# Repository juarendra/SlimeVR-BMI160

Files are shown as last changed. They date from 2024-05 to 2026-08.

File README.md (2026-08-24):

# SlimeVR-BMI160 DIY Tracker





**SlimeVR-BMI160** adalah proyek tracker full-body DIY (Do It Yourself) berbasis ESP32 dan sensor IMU BMI160, dikembangkan oleh [Positron Electronik](https://www.tokopedia.com/positronelectronic). Solusi ini merupakan alternatif hemat biaya dari tracker SlimeVR original, dengan tetap mempertahankan performa tinggi untuk pengalaman VR yang imersif.

<p align="center">
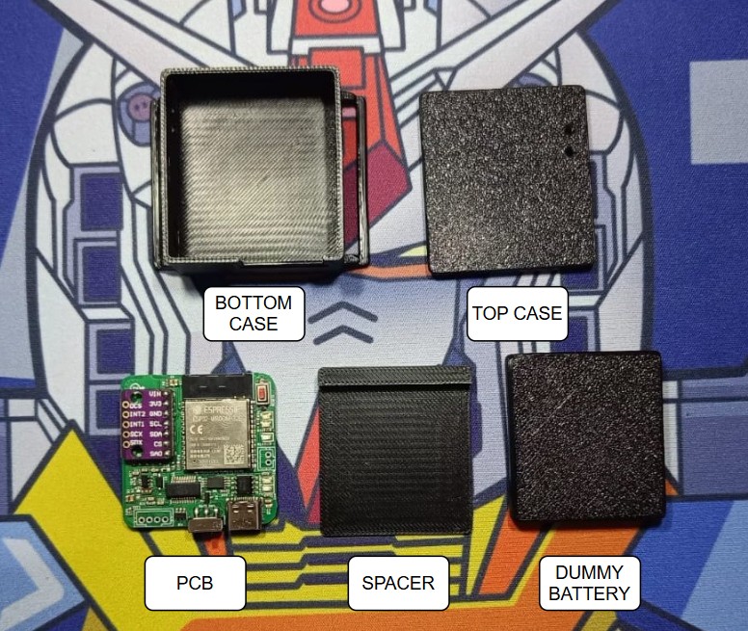
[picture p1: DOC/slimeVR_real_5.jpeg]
  
</p>

## ⚡ Fitur Unggulan
- **Mikrokontroler**: ESP32-WROOM-32 (WiFi + BLE)
- **Sensor IMU**: BMI160 (header socket, mudah diganti)
- **Manajemen Daya**: USB-C atau LiPo 1S, charger TP4056 + proteksi DW01A
- **Konektor I2C**: Port ekspansi untuk sensor tambahan
- **LED Indikator**: 5 LED untuk status pengisian, koneksi, dan serial
- **Tombol**: Reset & power switch

## 🚀 Cara Penggunaan

### 📦 Isi Paket (untuk produk jadi)
- 1 Unit tracker SlimeVR-BMI160
- 1 Baterai LiPo (terpasang)

### 🔋 Pengisian Daya
- Colokkan USB-C: LED **biru** menyala saat mengisi, **merah** saat penuh.

### 🌐 Flash & Konfigurasi WiFi (Metode Termudah)
Gunakan **Web Installer** tanpa instalasi software:
1. Buka [SlimeVR BMI160 Web Installer](https://juarendra.github.io/SlimeVR-BMI160/) di Chrome/Edge (PC).
2. Hubungkan tracker via USB.
3. Klik **Install Firmware**, lalu masukkan SSID & Password WiFi.
4. Tunggu hingga proses selesai dan tracker terhubung ke server SlimeVR.

> **Catatan**: Web Installer menggunakan Web Serial, jadi pastikan browser mendukung (Chrome/Edge).

### 🛠️ Metode Manual (untuk Developer)
Jika Anda ingin mengembangkan atau mengompilasi firmware sendiri, ikuti panduan lengkap di:
➡️ **[Panduan Flashing Manual](./FIRMWARE/README.md)**

## 📂 Struktur Repositori
| Direktori | Isi |
|---|-----|
| `/PCB` | Desain PCB (EAGLE) dan file Gerber |
| `/HARDWARE` | Model 3D case (STL) dan dimensi |
| `/FIRMWARE` | Source code firmware (PlatformIO) dan file .bin compiled |
| `/site` | Web Installer (HTML, CSS, JS, manifest) |
| `/DOC` | Dokumentasi, gambar, BOM, datasheet |
| `/scripts` | Script otomatisasi (QA, release) |

## 🔧 Untuk Pengembang (DIY)
Jika Anda ingin merakit sendiri:
1. **Rakit Hardware**: Gunakan file PCB dari `/PCB/CAD-CAM`, BOM dari `/DOC/BOM_SlimeVRDiyModular.csv`, dan case 3D dari `/HARDWARE/case`.
2. **Flash Firmware**: Ikuti panduan di `/FIRMWARE/README.md`.
3. **Verifikasi**: Gunakan serial monitor untuk memastikan koneksi WiFi dan sensor.

## 🐛 Pemecahan Masalah Umum
- **Tracker tidak muncul di server**: Pastikan SSID/password benar, PC dan tracker satu jaringan, saklar ON.
- **LED mati total**: Cek saklar, charge baterai via USB-C.

## 📖 Dokumentasi Lengkap
- [Dokumentasi Software (PDF)](./DOC/SOFTWARE_USAGE.pdf) — panduan detail penggunaan web installer dan manual.

<details>
<summary><strong>📐 Detail Teknis dan Galeri</strong></summary>

| Fitur | Komponen |
|---|---|
| Mikrokontroler | ESP32-WROOM-32 |
| Sensor IMU | BMI160 |
| USB-to-Serial | FTDI FT231XS |
| Charger | TP4056 |
| Proteksi Baterai | DW01A + FS8205A |
| Regulator | M3406 (3.3V 800mA) |

**Diagram Pinout**:
<p align="center">
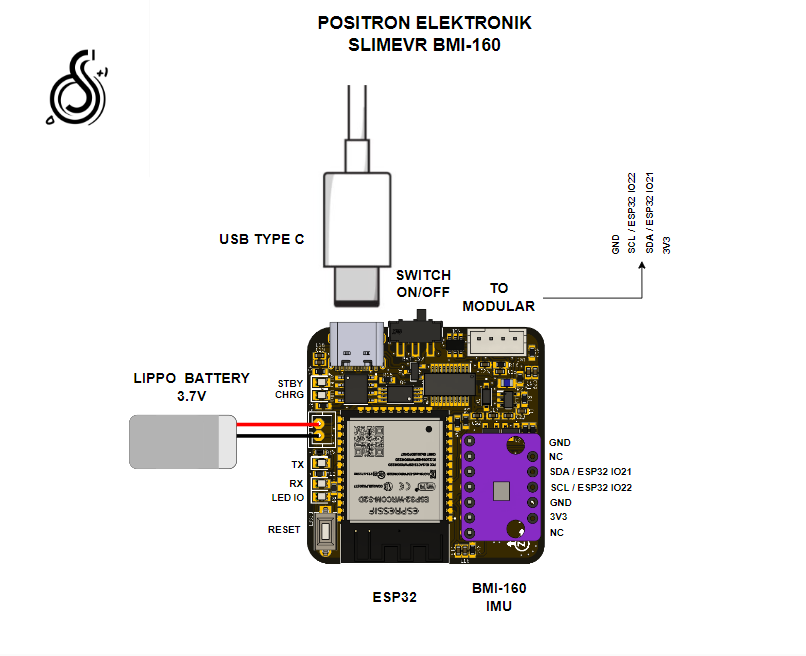
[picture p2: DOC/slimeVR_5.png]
  
</p>

**Dimensi Board**: [PDF](https://github.com/juarendra/SlimeVR-BMI160/blob/main/HARDWARE/dimension_SlimeVR.pdf)

**Galeri**:
<p align="center">
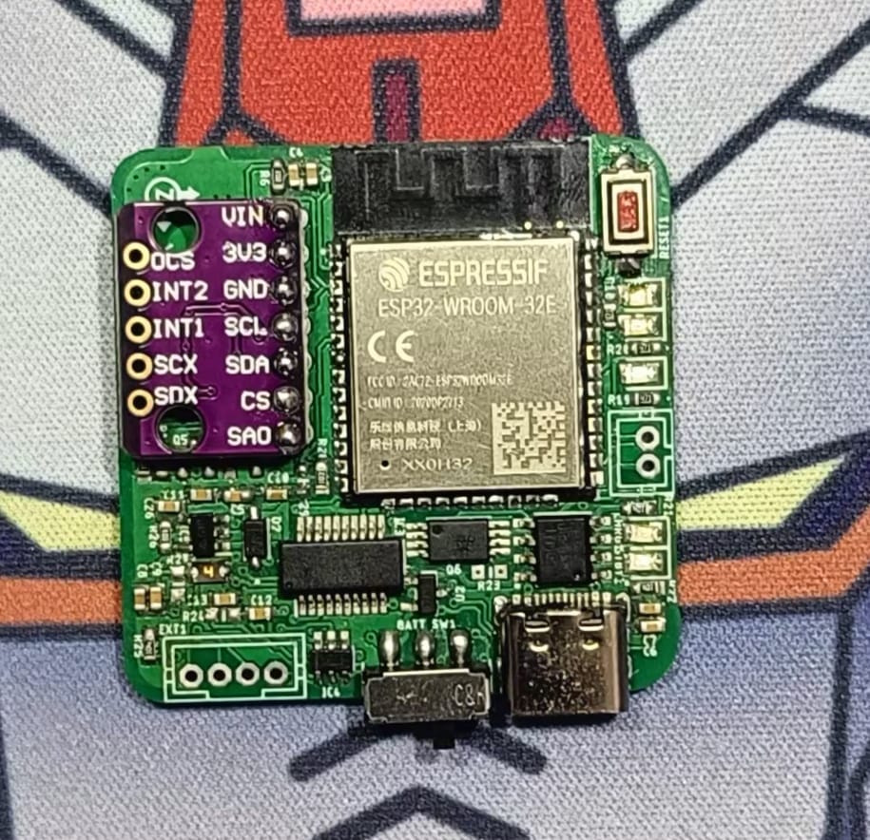
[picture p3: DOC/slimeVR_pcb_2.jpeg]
  
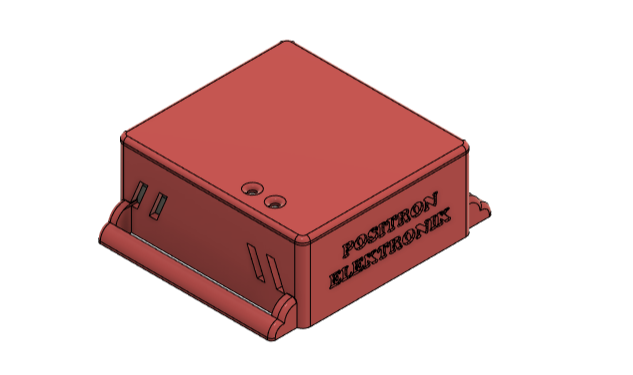
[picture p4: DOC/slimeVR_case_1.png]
  
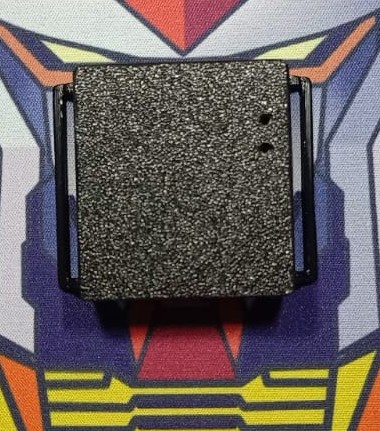
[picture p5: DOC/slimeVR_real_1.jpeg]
  
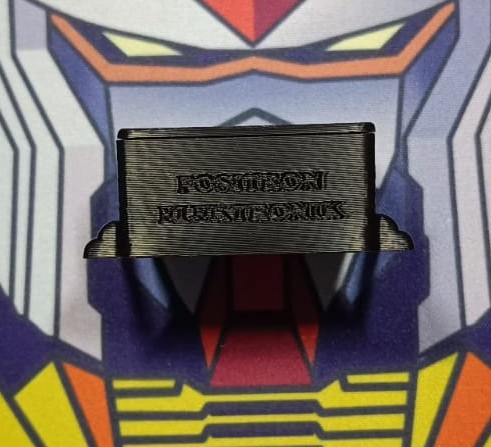
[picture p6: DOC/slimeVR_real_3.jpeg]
  
</p>
</details>

## ❓ FAQ
*Segera hadir.*

## 🤝 Kontribusi
Pull request dan saran sangat diterima! Silakan buka issue di GitHub.

## 📜 Lisensi
MIT License © 2024 Positron Electronik

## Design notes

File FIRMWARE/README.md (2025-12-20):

# Panduan Flashing Firmware SlimeVR untuk ESP32

Dokumen ini menjelaskan cara melakukan instalasi, konfigurasi, dan flashing firmware SlimeVR ke board ESP32 menggunakan Visual Studio Code dan PlatformIO.

## Daftar Isi
1. [Alat yang Dibutuhkan](#1-alat-yang-dibutuhkan)
2. [Instalasi Perangkat Lunak](#2-instalasi-perangkat-lunak)
    - [Download dan Instal Visual Studio Code](#a-download-dan-instal-visual-studio-code)
    - [Instal Ekstensi PlatformIO IDE](#b-instal-ekstensi-platformio-ide)
3. [Persiapan Firmware](#3-persiapan-firmware)
    - [Download Kode Firmware](#a-download-kode-firmware)
    - [Buka Proyek di VS Code](#b-buka-proyek-di-vs-code)
4. [Konfigurasi Wi-Fi (Hardcode)](#4-konfigurasi-wi-fi-hardcode)
5. [Proses Flashing](#5-proses-flashing)
    - [A. Hapus Flash (Erase Flash)](#a-hapus-flash-erase-flash---opsional-tapi-direkomendasikan)
    - [B. Upload Firmware](#b-upload-firmware)
6. [Monitoring dan Verifikasi](#6-monitoring-dan-verifikasi)
    - [Membuka Serial Monitor](#a-membuka-serial-monitor)
    - [Memahami Output Serial Monitor](#b-memahami-output-serial-monitor)

---

### 1. Alat yang Dibutuhkan
- **SLIMEVR By POSITRON ELECTRONIC**: Pastikan Anda memiliki board pengembangan ESP32.
- **Kabel USB**: Kabel data USB untuk menghubungkan ESP32 ke komputer.
- **Komputer**: PC atau laptop dengan sistem operasi Windows, macOS, atau Linux.

### 2. Instalasi Perangkat Lunak

#### a. Download dan Instal Visual Studio Code
Visual Studio Code (VS Code) adalah editor kode yang akan kita gunakan.
- **Download di sini**: [https://code.visualstudio.com/](https://code.visualstudio.com/)
- Instal VS Code sesuai dengan petunjuk untuk sistem operasi Anda.

#### b. Instal Ekstensi PlatformIO IDE
PlatformIO adalah sebuah _toolchain_ yang memudahkan pengembangan untuk perangkat keras _embedded_ seperti ESP32.
1. Buka VS Code.
2. Buka menu **Extensions** di sidebar kiri (ikon kotak).
3. Di kotak pencarian, ketik `PlatformIO IDE`.
4. Pilih ekstensi dari **PlatformIO** dan klik **Install**.
5. Tunggu hingga proses instalasi selesai. Ini mungkin memakan waktu beberapa menit karena PlatformIO akan menginstal banyak komponen. Setelah selesai, VS Code mungkin akan meminta untuk di-reload.

### 3. Persiapan Firmware

#### a. Download Kode Firmware
Firmware yang akan kita gunakan berasal dari repositori ini.
- **Download di sini**: [SlimeVR-BMI160 Firmware](https://github.com/juarendra/SlimeVR-BMI160/archive/refs/heads/main.zip)
- Ekstrak file ZIP yang sudah di-download. Anda akan mendapatkan folder `SlimeVR-BMI160-main`.

#### b. Buka Proyek di VS Code
1. Buka VS Code.
2. Klik **File** > **Open Folder...**.
3. Arahkan ke folder firmware yang telah Anda ekstrak, lalu buka `SlimeVR-BMI160-main\FIRMWARE\SlimeVR-Tracker-ESP`.
4. VS Code akan membuka proyek tersebut. PlatformIO mungkin akan mulai menginstal _library_ dan _toolchain_ yang dibutuhkan secara otomatis. Biarkan proses ini berjalan hingga selesai.

### 4. Konfigurasi Wi-Fi (Hardcode)
Untuk menghubungkan tracker ke jaringan Wi-Fi Anda, Anda perlu memasukkan nama (SSID) dan password Wi-Fi secara manual ke dalam file konfigurasi.
1. Di panel explorer VS Code (sidebar kiri), cari dan buka file `platformio.ini`.
2. Cari bagian `[env:esp32dev]`.
3. Di bawahnya, temukan `build_flags`.
4. Tambahkan atau ubah baris berikut di dalam `build_flags` untuk memasukkan informasi Wi-Fi Anda.

    ```ini
    [env:esp32dev]
    ; ... (konfigurasi lainnya)
    build_flags = 
        ; ... (flags lainnya)
        -DWIFI_SSID='"NAMA_WIFI_ANDA"'
        -DWIFI_PASSWORD='"PASSWORD_WIFI_ANDA"'
    ```
    **Ganti `NAMA_WIFI_ANDA` dan `PASSWORD_WIFI_ANDA`** dengan nama dan password Wi-Fi Anda yang sebenarnya. Pastikan untuk tetap menggunakan tanda kutip ganda di dalam dan di luar (`'"..."'`).

### 5. Proses Flashing
Hubungkan board ESP32 Anda ke komputer menggunakan kabel USB.

#### a. Hapus Flash (Erase Flash - Opsional tapi Direkomendasikan)
Menghapus flash sangat disarankan jika Anda baru pertama kali melakukan flash atau jika Anda mengubah konfigurasi Wi-Fi. Ini memastikan tidak ada konfigurasi lama yang tersisa.
1. Di bagian bawah jendela VS Code, cari toolbar PlatformIO.
2. Klik ikon centang (**✓**) untuk **Build** terlebih dahulu guna memastikan tidak ada eror.
3. Setelah build berhasil, klik **PlatformIO: Erase Flash**. Atau, buka terminal PlatformIO dengan mengklik ikon terminal (mirip `>_`) di toolbar, lalu ketik perintah:
    ```sh
    pio run --target erase
    ```
4. Tunggu hingga proses penghapusan selesai.

#### b. Upload Firmware
Setelah flash dihapus (atau jika Anda memilih untuk melewatinya), Anda dapat meng-upload firmware.
1. Di toolbar PlatformIO (bagian bawah jendela VS Code), klik ikon panah ke kanan (**→**) yang merupakan tombol **Upload**.
2. PlatformIO akan secara otomatis meng-compile (build) kode dan meng-upload-nya ke ESP32.
3. Anda akan melihat log proses di terminal. Jika berhasil, akan ada pesan `SUCCESS`.

### 6. Monitoring dan Verifikasi
Serial Monitor digunakan untuk melihat log dan status dari tracker ESP32 secara real-time.

#### a. Membuka Serial Monitor
1. Setelah proses upload berhasil, klik ikon steker (**🔌**) di toolbar PlatformIO untuk membuka **Serial Monitor**.
2. Pastikan baud rate (kecepatan) diatur ke **115200**. Biasanya ini sudah diatur secara otomatis.

#### b. Memahami Output Serial Monitor
Saat Serial Monitor terbuka, Anda akan melihat output teks dari ESP32. Berikut adalah contoh output dan penjelasannya:

```
[20:13:30] [INFO] [main] Starting SlimeVR tracker...
[20:13:30] [INFO] [main] SlimeVR v0.4.0
```
- **Penjelasan**: Tracker mulai berjalan dan menampilkan versi firmware.

```
[20:13:31] [INFO] [WIFI] Connecting to "NAMA_WIFI_ANDA"
...
[20:13:34] [INFO] [WIFI] WiFi connected. SSID: NAMA_WIFI_ANDA
[20:13:34] [INFO] [WIFI] IP address: 192.168.1.10
```
- **Penjelasan**: Tracker sedang mencoba terhubung ke jaringan Wi-Fi yang Anda konfigurasikan. Jika berhasil, ia akan menampilkan alamat IP yang didapat. Jika gagal, akan ada pesan error atau percobaan koneksi berulang.

```
[20:13:34] [INFO] [I2C] Scanning I2C bus...
[20:13:34] [INFO] [I2C] Found I2C device at address 0x68
[20:13:34] [INFO] [SENSOR] Found BMI160 at address 0x68
```
- **Penjelasan**: Tracker memindai sensor IMU (Inertial Measurement Unit) yang terhubung melalui I2C. Dalam kasus ini, ia berhasil menemukan sensor BMI160 di alamat `0x68`. Jika sensor tidak terdeteksi, Anda akan melihat pesan error.

```
[20:13:35] [INFO] [SERVER] Trying to connect to server at 192.168.1.255:6969...
[20:13:35] [INFO] [SERVER] Connected to server!
```
- **Penjelasan**: Tracker mencari dan mencoba terhubung ke server SlimeVR di jaringan lokal Anda. Setelah terhubung, ia siap mengirim data.

```
[20:13:36] [INFO] [OUTPUT:0] Sensor 0 reporting: 1.00 0.00 0.00 0.00
```
- **Penjelasan**: Ini adalah data rotasi (dalam bentuk quaternion) yang dikirim oleh sensor ke server. Anda akan melihat pesan ini berulang kali saat tracker aktif.

Jika Anda melihat semua log ini (koneksi Wi-Fi berhasil, sensor terdeteksi, dan terhubung ke server), maka proses flashing dan konfigurasi Anda telah berhasil!

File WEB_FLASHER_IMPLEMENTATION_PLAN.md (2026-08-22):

# SlimeVR BMI160 Web Flasher Implementation Plan

## 1. Goal

Build and host a static web installer for Positron Electronic SlimeVR BMI160 trackers at:

```text
https://juarendra.github.io/SlimeVR-BMI160/
```

User flow:

1. Open site in supported desktop browser.
2. Connect ESP32 tracker through USB.
3. Flash one public, hardware-specific firmware build.
4. Enter 2.4 GHz WiFi SSID and password in browser.
5. Browser sends credentials directly to tracker over local USB serial.
6. Tracker persists credentials in ESP32 NVS and connects to WiFi.
7. Site confirms connection without sending credentials to GitHub or any server.

Firmware must retain repository-specific settings:

- ESP32 WROOM board.
- BMI160 IMU.
- `IMU_ROTATION DEG_180`.
- GPIO configuration from `src/defines.h`.
- Battery divider `R1 = 1.0 kOhm`, `R2 = 1.82 kOhm`.

## 2. Non-Goals

Do not implement these in first release:

- Compiling firmware in browser.
- Patching SSID/password strings inside `.bin` files.
- Sending WiFi credentials to GitHub Actions or any remote API.
- Captive portal, SoftAP configuration, or mobile flashing.
- Support for boards other than this repository's ESP32 WROOM + BMI160 profile.
- OTA firmware updates from website.
- User accounts, analytics, cookies, telemetry, or backend service.
- React, Vue, Next.js, Vite, Tailwind, package manager, or frontend build framework.

Reason: static HTML/CSS/JavaScript plus ESP Web Tools and existing serial protocol covers required flow with fewer failure modes.

## 3. Mandatory Security Gate

Do not publish or deploy firmware until all items below pass.

### 3.1 Rotate exposed WiFi passwords

Two private WiFi credential sets already exist in public source, Git history, and/or compiled firmware. Exact values are intentionally omitted from this plan.

Treat both passwords as compromised. Owner must change both router passwords before implementation continues. Git cleanup cannot make old passwords safe again.

### 3.2 Remove private credentials from public build

In `FIRMWARE/SlimeVR-Tracker-ESP/platformio.ini`, comment out or delete active flags:

```ini
-DWIFI_CREDS_SSID='"..."'
-DWIFI_CREDS_PASSWD='"..."'
```

Keep commented examples only:

```ini
;  -DWIFI_CREDS_SSID='"YOUR_WIFI_SSID"'
;  -DWIFI_CREDS_PASSWD='"YOUR_WIFI_PASSWORD"'
```

Public firmware must first try saved NVS credentials, then remain available for USB provisioning. It must never contain owner/customer credentials.

### 3.3 Replace credential-bearing compiled firmware

Existing `FIRMWARE/Compiled/BMI-160/firmware.bin` contains exposed WiFi credentials. Do not deploy it.

Preferred action:

- Remove manually committed generated binaries from active distribution.
- Build sanitized binaries in GitHub Actions.
- Publish only CI-built artifacts and Pages deployment output.

If binaries remain in repository for compatibility, replace them with sanitized CI output and document source commit plus SHA-256.

### 3.4 Secret checks

Before first deployment, scan current files and full history:

```powershell
gitleaks detect --source .
gitleaks detect --source . --log-opts="--all"
```

Current-tree scan must have no unresolved finding. Full-history findings for already-rotated credentials must be recorded in a reviewed baseline; CI then fails on any finding not in that immutable baseline. Never broadly allowlist paths or secret types. Also scan built firmware strings using exact leaked values supplied through a local, uncommitted denylist during remediation. Production CI must verify generic WiFi values are absent and fail on any current secret finding.

History rewrite is optional after password rotation and requires separate owner approval. Do not force-push history during this task unless explicitly approved.

## 4. Chosen Architecture

### 4.1 Flashing

Use ESP Web Tools for browser-to-ESP32 flashing. ESP Web Tools uses Web Serial and `esptool-js`, handles ESP bootloader control, progress, erase prompts, and serial port lifecycle.

Site supplies an ESP Web Tools manifest containing one sanitized merged ESP32 image at offset `0`.

Build merged image with pinned Espressif `esptool merge-bin`. Source component addresses and flash parameters from PlatformIO's generated upload command or board metadata, then compare them in verification. Current expected component layout is:

```text
0x1000   bootloader.bin
0x8000   partitions.bin
0xE000   boot_app0.bin
0x10000  firmware.bin
```

Never guess offsets or flash mode/frequency/size from this plan alone. Packaging must fail if generated metadata differs from expected values. ESP Web Tools manifest contains only merged image:

```text
offset 0   slimevr-bmi160-esp32-full.bin
```

### 4.2 WiFi provisioning

Use existing firmware serial command:

```text
SET BWIFI <BASE64_SSID> <BASE64_PASSWORD>\n
```

Relevant implementation:

- `FIRMWARE/SlimeVR-Tracker-ESP/src/serial/serialcommands.cpp`
- `FIRMWARE/SlimeVR-Tracker-ESP/src/network/wifihandler.cpp`

Why `SET BWIFI`, not `SET WIFI`:

- SSID and password may contain spaces or quotes.
- Base64 avoids command-parser quoting ambiguity.
- Browser can encode UTF-8 bytes before Base64.

Firmware must provide stable machine-readable responses without SSID/password:

```text
[WIFI-PROVISION] ACCEPTED
[WIFI-PROVISION] CONNECTED <IP>
[WIFI-PROVISION] FAILED <ERROR_CODE>
```

Allowed error codes are fixed identifiers such as `INVALID_INPUT`, `AUTH_TIMEOUT`, and `NETWORK_UNAVAILABLE`; never include credentials. `ACCEPTED` means input accepted, not network connected. Browser accepts success only from post-command `CONNECTED` response for current attempt.

### 4.3 Hosting

Use GitHub Pages through GitHub Actions. Deploy only generated `dist/` content. Never deploy repository root.

Site is static. WiFi credentials stay in page memory and travel only over local Web Serial.

## 5. Repository Layout

Create this minimum layout:

```text
SlimeVR-BMI160/
├── .github/
│   └── workflows/
│       └── pages.yml
├── site/
│   ├── index.html
│   ├── styles.css
│   ├── app.js
│   ├── manifest.json
│   ├── assets/
│   │   ├── board-mark.svg
│   │   └── favicon.svg
│   └── vendor/
│       └── esp-web-tools/
│           └── install-button.js
├── scripts/
│   ├── prepare_pages.py
│   └── verify_release.py
├── FIRMWARE/
│   └── SlimeVR-Tracker-ESP/
├── WEB_FLASHER_IMPLEMENTATION_PLAN.md
└── README.md
```

Generated deployment directory, never commit:

```text
dist/
├── index.html
├── styles.css
├── app.js
├── manifest.json
├── assets/
├── vendor/
└── firmware/
    └── <release-id>/
        ├── slimevr-bmi160-esp32-full.bin
        └── SHA256SUMS.txt
```

Create root `.gitignore` before packaging and add `/dist/`. Do not use lowercase `docs/`; repository already has uppercase `DOC/`, which conflicts on Windows case-insensitive filesystems.

## 6. Firmware Work

### 6.1 Sanitize build configuration

Edit `FIRMWARE/SlimeVR-Tracker-ESP/platformio.ini`:

1. Remove active WiFi credentials.
2. Preserve `[env:esp32]` settings.
3. Do not inject GitHub secrets into firmware build.
4. Keep OTA disabled for initial public web-flasher release unless owner explicitly defines fleet OTA policy.

### 6.2 Preserve custom hardware settings

Verify `FIRMWARE/SlimeVR-Tracker-ESP/src/defines.h` still contains:

```cpp
#define IMU IMU_BMI160
#define BOARD BOARD_WROOM32
#define IMU_ROTATION DEG_180
#define MAX_IMU_COUNT 1
#define BATTERY_MONITOR BAT_EXTERNAL
#define BATTERY_SHIELD_RESISTANCE 0
#define BATTERY_SHIELD_R1 1.0
#define BATTERY_SHIELD_R2 1.82
#define PIN_IMU_SDA 21
#define PIN_IMU_SCL 22
#define PIN_IMU_INT 23
#define PIN_BATTERY_LEVEL 34
```

Do not generalize these into user-selectable website options in first release.

### 6.3 Harden serial credential handling

Review and minimally fix these before publishing:

1. Reject malformed Base64 alphabet, padding, and length before decoding.
2. Reject encoded input large enough to allocate decoded buffers beyond SSID/password ceilings; never create variable-length stack arrays from unchecked input.
3. Decode into fixed-size arrays: SSID 33 bytes, password 65 bytes.
4. Validate decoded SSID is 1-32 bytes and password follows selected network-security policy.
5. Reject embedded decoded NUL, CR, and LF.
6. Ensure decoded buffers are always null-terminated.
7. Ensure command never prints raw SSID/password, Base64 credentials, or connected SSID.
8. Keep response text stable for browser parser.
9. Ensure a second `SET BWIFI` attempt works after first password fails.
10. Fix ESP32 `SLIME_WIFI_SERVER_CRED_ATTEMPT` timeout state so it does not remain stuck forever after failed credentials.
11. Add tracker identity response for `GET INFO` containing stable non-secret marker, firmware version, hardware profile, and protocol version.

Keep protocol backward-compatible. Do not add a new provisioning library in version 1.

Required stable machine-readable responses:

```text
[WIFI-PROVISION] ACCEPTED
[WIFI-PROVISION] CONNECTED <IP>
[WIFI-PROVISION] FAILED <ERROR_CODE>
```

Do not include SSID or password in these lines. Do not parse human logger text for provisioning success.

Version 1 network policy:

- Support WPA/WPA2 passphrases containing 8-63 UTF-8 bytes.
- Support 64-byte raw PSK only when every byte is ASCII hexadecimal.
- Do not advertise open-network support in version 1.
- Reject password lengths 0-7 and invalid 64-byte values before calling `WiFi.begin`.

### 6.4 Firmware checks

Run:

```powershell
pio run -e esp32
```

From:

```text
FIRMWARE/SlimeVR-Tracker-ESP
```

Required checks:

- Build exits `0`.
- `firmware.bin` fits `app0` partition.
- `esptool image-info` accepts bootloader and firmware images.
- Built binary does not contain known private SSID/password values.
- Serial `SET BWIFI` succeeds with SSID containing spaces.
- Oversized/malformed Base64, embedded NUL, and invalid password lengths are rejected without changing NVS or connection state.
- Wrong password can be retried without reflashing or rebooting.
- Correct credentials survive reboot through ESP32 NVS.

## 7. Website Behavior

### 7.1 State machine

Implement explicit states in `site/app.js`. Never infer UI state from button text.

```text
UNSUPPORTED_BROWSER
READY_TO_FLASH
FLASHING
FLASH_CANCELLED
FLASH_FAILED
FLASH_COMPLETE
READY_TO_PROVISION
SERIAL_CONNECTING
DEVICE_VERIFYING
DEVICE_REJECTED
SENDING_CREDENTIALS
WAITING_FOR_WIFI
CONNECTED
PROVISION_FAILED
DEVICE_DISCONNECTED
```

Only one state may be active. A single `renderState(state, detail)` function updates status label, progress, enabled controls, instructions, and live region.

Transitions:

```text
READY_TO_FLASH -> FLASHING -> FLASH_COMPLETE
FLASHING -> FLASH_CANCELLED | FLASH_FAILED
FLASH_COMPLETE -> READY_TO_PROVISION
READY_TO_FLASH -> READY_TO_PROVISION (explicit "Configure existing firmware" action)
READY_TO_PROVISION -> SERIAL_CONNECTING -> DEVICE_VERIFYING
DEVICE_VERIFYING -> SENDING_CREDENTIALS | DEVICE_REJECTED
SENDING_CREDENTIALS -> WAITING_FOR_WIFI
WAITING_FOR_WIFI -> CONNECTED
WAITING_FOR_WIFI -> PROVISION_FAILED
any connected state -> DEVICE_DISCONNECTED
PROVISION_FAILED -> READY_TO_PROVISION
FLASH_CANCELLED | FLASH_FAILED -> READY_TO_FLASH
DEVICE_REJECTED | DEVICE_DISCONNECTED -> READY_TO_PROVISION
```

### 7.2 Browser support gate

On load, test:

```js
window.isSecureContext && "serial" in navigator
```

Published support statement:

```text
Version 1 support: current desktop Google Chrome or Microsoft Edge on Windows.
Other operating systems, Safari, Firefox, and mobile browsers are not yet supported.
```

Do not hide unsupported state. Show direct instructions and disable flashing/provisioning actions.

### 7.3 Flash step

Use:

```html
<esp-web-install-button manifest="./manifest.json"></esp-web-install-button>
```

Requirements:

- User explicitly clicks Connect/Install.
- Manifest profile label says `Positron SlimeVR BMI160 (ESP32 WROOM)`.
- Warn that wrong hardware profile may require recovery.
- Explain whether erase preserves or removes calibration and old WiFi credentials.
- ESP Web Tools install button has no assumed host-page success event. Do not infer success from dialog close.
- Keep page state at flash operation while native dialog is open. After native dialog itself reports success, user explicitly clicks `Firmware installed - continue` to enter provisioning. Label makes this confirmation clear; it does not claim independent verification.
- Cancel/failure returns to flash instructions. Never mark dialog closure alone as success.
- After flash, instruct user to wait for USB serial port to reappear before provisioning.
- Always show secondary `Configure existing firmware` action so reload does not force another flash.

### 7.4 WiFi form

Fields:

- `SSID`, text input, required, `autocomplete="off"`, `spellcheck="false"`.
- `Password`, password input, required, `autocomplete="new-password"`.
- Show/hide password button with accessible label and `aria-pressed`.
- `Connect WiFi` primary button.

Validation:

- Trim neither SSID nor password; spaces can be valid.
- Encode input with `TextEncoder`.
- Validate encoded SSID byte length is 1-32.
- Validate WPA/WPA2 password as 8-63 UTF-8 bytes, or exactly 64 ASCII hexadecimal bytes.
- Reject `\r`, `\n`, and NUL before Base64 encoding.
- Report field-level error text linked with `aria-describedby`.
- Never include input values in errors.

Base64 helper must encode bytes, not JavaScript UTF-16 code units. Use a chunk-safe byte-to-binary conversion rather than `btoa(value)` directly.

### 7.5 Web Serial provisioning

Provisioning algorithm:

1. User clicks `Connect WiFi`; this user gesture calls `navigator.serial.requestPort()`.
2. Open selected port at `115200` baud.
3. Start read loop with `TextDecoderStream` or chunk-aware `TextDecoder`.
4. Accumulate serial data and split complete lines on `\n`; keep partial trailing line.
5. Discard startup lines from provisioning matcher, then send `GET INFO\n`.
6. Require stable tracker identity marker, expected `ESP32_WROOM_BMI160` hardware profile, and supported provisioning protocol version. Reject unknown/mismatched serial device before credentials are encoded or sent.
7. Encode SSID/password to UTF-8 bytes, then Base64.
8. Start a new attempt ID in page memory, reset matcher, and write exactly one command ending in LF:

   ```text
   SET BWIFI <base64-ssid> <base64-password>\n
   ```

9. Do not print command to console or UI.
10. Wait up to 5 seconds for post-command `[WIFI-PROVISION] ACCEPTED`.
11. After acknowledgment, wait up to 30 seconds for post-ack `[WIFI-PROVISION] CONNECTED <IP>` or `[WIFI-PROVISION] FAILED <ERROR_CODE>`.
12. Ignore stale connection lines received before current command acknowledgment.
13. On success, clear SSID/password variables and inputs.
14. On failure/timeout, retain SSID for convenience, always clear password and encoded password bytes, and show retry guidance without claiming exact cause unless firmware supplied a defined error code.
15. In `finally`, release reader/writer locks and close port unless keeping it open is required for active confirmation.

Open networks are unsupported in version 1. UI and firmware reject empty password.

Port handling:

- Handle chooser cancellation by returning to `READY_TO_PROVISION`, not fatal.
- Handle port already open by serial monitor.
- Handle USB disconnect during read/write.
- Handle board reset and USB re-enumeration after flash.
- Never automatically select an unconfirmed port for destructive flash.
- Never send credentials before successful device identity handshake.

### 7.6 Privacy behavior

Code must not use:

- `fetch()` for credentials.
- Query parameters or URL fragments for credentials.
- `localStorage`, `sessionStorage`, IndexedDB, cookies, Cache API, or service workers for credentials.
- Console logging of form values or serial command.
- Analytics, error-reporting SDKs, chat widgets, remote fonts, or third-party scripts.

After success, disconnect, or page unload:

- Set input values to empty strings.
- Clear encoded arrays where practical with `.fill(0)`.
- Drop command string references.

After provisioning failure, retain only SSID input; clear password and all encoded credential/command buffers.

## 8. UI Design Direction

### 8.1 Visual identity: Precision Electronics Workbench

Avoid generic SaaS dashboard, giant gradient headline, floating glass cards, excessive pills, and random glowing blobs.

Use visual language inspired by:

- PCB silkscreen labels.
- Bench instruments.
- Calibration sheets.
- Connector pin numbering.
- Restrained status LEDs.

Page should feel like trusted hardware tooling, not marketing landing page.

### 8.2 Layout

Desktop, `>= 960px`:

```text
┌──────────────────────────────────────────────────────────────┐
│ POSITRON / DEVICE UTILITY                  ESP32 · BMI160     │
├───────────────────┬──────────────────────────────────────────┤
│ Step rail         │ Active operation panel                   │
│ 01 Inspect        │ Title + exact instruction                │
│ 02 Flash          │ Device illustration / controls           │
│ 03 WiFi           │ Progress or form                         │
│ 04 Verify         │ Technical status transcript              │
├───────────────────┴──────────────────────────────────────────┤
│ Privacy statement · firmware version · source commit         │
└──────────────────────────────────────────────────────────────┘
```

- Max content width: `1120px`.
- Left rail: `240px`; right panel fills remaining width.
- Primary content left-aligned.
- Keep operation card visible above fold at 1366x768.
- Use CSS grid, no JavaScript layout.

Mobile, `< 760px`:

- Single column.
- Step rail becomes horizontal numbered strip with overflow-safe labels.
- Inputs and buttons use full width.
- Minimum touch target `44px`.
- No horizontal page scroll at `320px` width.

Tablet, `760px-959px`:

- Single main column with compact horizontal step rail.
- Use two-column form rows only when each field remains at least `280px` wide; otherwise stack fields.
- No fixed left rail.

### 8.3 Color tokens

Use one restrained palette:

```css
:root {
  --ink-950: #0b0e0d;
  --ink-900: #111614;
  --ink-850: #171d1a;
  --ink-800: #1e2622;
  --line: rgba(226, 232, 228, 0.12);
  --paper: #e8ece9;
  --muted: #98a39d;
  --signal: #b8f35a;
  --signal-dark: #263b18;
  --copper: #d58a52;
  --warning: #f2b84b;
  --danger: #ef6a62;
  --success: #70d49b;
}
```

Rules:

- Near-black green-gray background, not pure black.
- Off-white text, not pure white.
- Acid-lime signal color only for primary action, current step, and success detail.
- Copper only for small hardware accents.
- No rainbow gradients.
- Status always has icon/text, never color alone.

### 8.4 Typography

No external font requests. Use local system stacks:

```css
--font-ui: "Segoe UI Variable", "Segoe UI", system-ui, sans-serif;
--font-mono: "Cascadia Code", "SFMono-Regular", Consolas, monospace;
```

Hierarchy:

- Utility eyebrow: 12px mono, uppercase, `0.12em` tracking.
- Main heading: `clamp(32px, 5vw, 58px)`, weight 650, tight line height.
- Operation title: 24-30px.
- Body: 16px, max line length `65ch`.
- Technical status: 13-14px mono with tabular numbers.

Avoid using five unrelated font sizes. Define type tokens once.

### 8.5 Distinctive visual elements

Implement with CSS/SVG only:

- Thin PCB-trace line connecting step numbers.
- Optional after end-to-end acceptance: small board silhouette based on actual tracker proportions, not stock robot art.
- Optional after end-to-end acceptance: corner registration marks around active operation panel.
- Monospace hardware labels: `MCU/ESP32`, `IMU/BMI160`, `LINK/USB`.
- One restrained status LED beside live connection state.

Do not add decorative charts, fake statistics, 3D mockups, mascots, or generic shield icons.

### 8.6 Components

Required components:

- Header identity strip.
- Browser compatibility banner.
- Four-step progress rail.
- Firmware identity block showing hardware, version, Git commit, and binary checksum link.
- Flash action area wrapping ESP Web Tools button.
- WiFi credential form.
- Status transcript showing fixed allowlisted events only. Never insert raw serial text; render with `textContent`, never `innerHTML`.
- Recovery/help disclosure using native `<details>`.
- Footer privacy statement and source link.

Buttons:

- One filled primary action per state.
- Secondary actions use transparent surface and subtle line.
- Disable buttons during async operations.
- Visible `:focus-visible` ring, at least 2px.
- Hover movement maximum 1px; no bouncing or large scale animation.

### 8.7 Motion

- 160-220ms transitions for opacity, border color, and transform only.
- Progress bar may animate width.
- Status LED may use one subtle pulse only while waiting.
- Respect `prefers-reduced-motion: reduce` and disable nonessential motion.
- No perpetual background animation.

### 8.8 Accessibility

- Semantic landmarks: `header`, `main`, `nav`, `section`, `footer`.
- Form uses real `<label>` elements.
- Async status uses `role="status" aria-live="polite"`.
- Errors use `role="alert"` when immediate.
- Current step uses `aria-current="step"`.
- Contrast: WCAG AA minimum.
- Keyboard-only flow must complete all non-browser-native actions.
- Do not override ESP Web Tools dialog accessibility.
- Password reveal button must not steal or reset field value.

## 9. Static Assets and Dependency Policy

### 9.1 ESP Web Tools

Prefer self-hosting a pinned release of `install-button.js` and its required module graph under `site/vendor/esp-web-tools/`.

Execution rules:

1. Select a specific tested ESP Web Tools version.
2. Record version and upstream URL in `site/vendor/esp-web-tools/README.md`.
3. Preserve upstream license notices.
4. Do not use unpinned `@latest` CDN URL.
5. If self-hosting module graph proves impractical, pin exact package version on CDN and document temporary exception. Never use floating version.

No other runtime third-party JavaScript.

### 9.2 Content Security Policy

GitHub Pages cannot freely set all response headers. Add a restrictive HTML CSP meta tag compatible with actual module loading:

```html
<meta http-equiv="Content-Security-Policy"
      content="default-src 'self'; script-src 'self'; style-src 'self'; img-src 'self' data:; connect-src 'self'; object-src 'none'; base-uri 'none'; form-action 'none'">
```

`frame-ancestors` is intentionally omitted because browsers ignore it in CSP meta tags and GitHub Pages cannot set custom CSP response headers. Document clickjacking-header limitation. Adjust other directives only if pinned ESP Web Tools dependency requires it. Do not add `unsafe-eval`. Avoid inline scripts/styles so `unsafe-inline` is unnecessary.

## 10. Manifest and Firmware Packaging

### 10.1 Manifest

`site/manifest.json` should resemble:

```json
{
  "name": "Positron SlimeVR BMI160",
  "version": "<release-id>",
  "new_install_prompt_erase": true,
  "new_install_improv_wait_time": 0,
  "builds": [
    {
      "chipFamily": "ESP32",
      "serialType": "uart",
      "parts": [
        { "path": "./firmware/<release-id>/slimevr-bmi160-esp32-full.bin", "offset": 0 }
      ]
    }
  ]
}
```

`new_install_improv_wait_time` is `0` because version 1 uses custom `SET BWIFI`, not Improv Serial.

Generate canonical release ID once from short Git commit, for example:

```text
positron-abc1234
```

Do not hand-edit release IDs in multiple files. Packaging script receives full commit SHA, derives `positron-<short-sha>`, and writes same value to manifest, page metadata, artifact directory, and checksum metadata. Firmware's existing embedded Git version remains separate and must report same full source commit through `GET INFO`.

### 10.2 Packaging script

Implement `scripts/prepare_pages.py` with Python 3.11. Do not add an alternative PowerShell path. Responsibilities:

1. Accept build directory, site directory, output directory, and release ID parameters.
2. Verify parent/output paths before creating directories.
3. Delete only generated output directory passed explicitly; guard against empty/root path.
4. Copy static site files into `dist/`.
5. Read exact PlatformIO upload metadata and locate bootloader, partition, `boot_app0`, and app images.
6. Invoke pinned `esptool merge-bin` with verified chip, addresses, flash mode, flash frequency, and flash size.
7. Write one merged image into immutable version directory.
8. Generate manifest at offset `0`.
9. Generate SHA-256 file.
10. Replace only declared release placeholders.
11. Exit nonzero on missing files, metadata mismatch, duplicate manifest profiles, or stale credentials.

Do not use script to edit tracked firmware source.

### 10.3 Verification script

Implement `scripts/verify_release.py` with Python 3.11. It must check:

- Every manifest path exists under `dist/`.
- Manifest has exactly one image at integer offset `0`.
- `chipFamily` equals `ESP32`.
- Firmware version in page and manifest match.
- SHA-256 file matches binaries.
- Known exposed credentials do not occur in text or binary output.
- No absolute local Windows paths occur in deployed text files.
- No remote scripts/fonts/images occur unless explicitly allowlisted.
- No source maps containing secrets are emitted.

## 11. GitHub Actions

Create `.github/workflows/pages.yml` with three jobs.

### 11.1 Triggers

```yaml
on:
  pull_request:
  push:
    branches: [main]
  workflow_dispatch:
```

### 11.2 `firmware` job

Responsibilities:

1. Checkout repository.
2. Set up pinned Python version `3.11`.
3. Install pinned PlatformIO `6.1.19`.
4. Cache PlatformIO packages keyed by OS and firmware config hashes.
5. Build only `esp32` environment from active firmware directory.
6. Run image and secret checks.
7. Upload sanitized firmware artifacts for later job.

Working directory:

```text
FIRMWARE/SlimeVR-Tracker-ESP
```

Build command:

```text
pio run -e esp32
```

### 11.3 `site-test` job

Depends on `firmware`.

Responsibilities:

1. Download firmware artifact.
2. Run `python scripts/prepare_pages.py`.
3. Run `python scripts/verify_release.py`.
4. Validate HTML.
5. Serve `dist/` locally and run browser-independent smoke checks for HTTP 200 on page, manifest, and every binary.
6. Upload `dist/` as Pages artifact only on `main`, not pull requests.

### 11.4 `deploy` job

Conditions:

```text
github.ref == refs/heads/main
event is push or workflow_dispatch
firmware and site-test succeeded
```

Set workflow-level default `permissions: { contents: read }`. Only `deploy` job receives:

```yaml
permissions:
  contents: read
  pages: write
  id-token: write
```

Use GitHub Pages environment and deployment concurrency group. Deploy only `dist/`.

### 11.5 Supply-chain requirements

- Pin GitHub Actions to reviewed full commit SHAs before production.
- Add comments showing friendly action version beside SHA.
- Pin PlatformIO and firmware Git dependencies to tags or commit SHAs.
- Do not expose repository secrets to pull requests.
- Do not build customer-specific credentials in CI.

## 12. Documentation Updates

### 12.1 Root README

Update WiFi section. Remove false statement that every SSID change requires firmware reflash.

New primary path:

1. Open hosted web flasher.
2. Flash generic custom firmware.
3. Provision WiFi over USB from same page.

Keep PlatformIO manual path under developer documentation.

Add:

- Hosted site URL.
- Supported browser/OS statement.
- Supported hardware profile.
- 2.4 GHz WiFi requirement.
- Privacy statement: credentials remain local in browser-to-device serial connection.
- Recovery link.

### 12.2 Firmware guide

Edit exactly `FIRMWARE/README.md`.

Correct current documentation mismatches:

- Environment is `[env:esp32]`, not `[env:esp32dev]`.
- Macros are `WIFI_CREDS_SSID` and `WIFI_CREDS_PASSWD`, not `WIFI_SSID` and `WIFI_PASSWORD`.
- Hardcoding is developer fallback, not recommended customer flow.
- Document `SET BWIFI` only as technical recovery interface; do not ask normal users to type Base64.

`FIRMWARE/SlimeVR-Tracker-ESP/README.md` remains upstream firmware documentation. `FIRMWARE/SlimeVR-Tracker-ESP-0.4.0/` is legacy/non-authoritative and must not be edited or built.

### 12.3 Site recovery instructions

Include concise recovery `<details>` sections:

- Browser cannot see serial port.
- Driver/USB cable issue.
- Serial port is busy in PlatformIO/SlimeVR Server.
- Flash failed midway.
- Wrong WiFi password.
- WiFi is 5 GHz only.
- Tracker does not appear in SlimeVR Server.

Do not blame user. Give exact next action per case.

## 13. Test Plan

### 13.1 Automated firmware tests

- Clean build on fresh GitHub runner.
- Verify binary image metadata.
- Verify app size fits partition.
- Verify known credentials absent.
- Verify merged-image source addresses and flash parameters match PlatformIO upload metadata; verify manifest offset is `0`.
- Verify deterministic static site packaging.

### 13.2 JavaScript unit-level checks

Without adding test framework, create a small browser-runnable assertion file only if helpers become non-trivial. Required cases:

- UTF-8 Base64 for ASCII.
- UTF-8 Base64 for non-ASCII SSID.
- 32-byte SSID accepted; 33-byte rejected.
- 8-byte and 63-byte passphrases accepted; 1-7 and 65-byte values rejected.
- 64-byte ASCII hexadecimal PSK accepted; non-hex 64-byte value rejected.
- Newline and NUL rejected.
- Malformed/oversized Base64 rejected before allocation and without NVS changes.
- Serial line parser handles split chunks.
- Serial line parser handles multiple lines in one chunk.
- Stale pre-command success line cannot satisfy current attempt.
- Unknown serial device is rejected before credential encoding/transmission.
- Credential command is never passed to transcript logger.

### 13.3 Browser tests

Required before release:

- Latest Chrome desktop on Windows.
- Latest Edge desktop on Windows.
- Unsupported state in Safari or browser without Web Serial.
- Port chooser cancel.
- Port busy by serial monitor.
- USB disconnect during flash.
- USB disconnect during provisioning.
- Page reload between flash and provisioning.
- Keyboard-only operation.
- `prefers-reduced-motion` behavior.
- Responsive layout at 320, 375, 768, 1024, and 1440 px widths.

### 13.4 Hardware tests

Use actual production board with FTDI FT231XS plus at least one spare/recovery board.

Scenarios:

1. Blank ESP32 flash.
2. Existing repository firmware without erase.
3. Existing firmware with full erase.
4. Correct WiFi credentials.
5. Wrong password followed by corrected password.
6. SSID containing spaces.
7. Maximum allowed SSID/password byte lengths.
8. Reboot after successful provisioning.
9. Router unavailable during setup, then available.
10. Power loss during flash, then ROM bootloader recovery.

Erase expectations:

- Recommend full erase for first install or recovery. It removes NVS WiFi credentials and LittleFS calibration; UI must warn before user opens installer.
- Non-erase install is advanced path. Verify app updates while existing NVS/LittleFS remain; never promise preservation until physical test passes.
- Record both outcomes in release evidence.

Verify after connection:

- Tracker receives DHCP IP.
- Credentials survive reboot.
- BMI160 initializes.
- Orientation remains correct.
- Battery debug/result matches expected divider.
- Tracker appears in SlimeVR Server.

### 13.5 Privacy tests

With browser DevTools open:

- Network panel contains no SSID/password.
- Console contains no SSID/password or Base64 equivalents.
- Application storage contains no credentials.
- URL never changes to include credentials.
- Page source and deployed binaries contain no owner/customer credentials.

## 14. Acceptance Criteria

Release is complete only when all criteria pass:

- GitHub Pages loads over HTTPS at project URL.
- Desktop Chrome and Edge show supported installer.
- Unsupported browsers show clear non-destructive guidance.
- Correct firmware profile is clearly identified as ESP32 WROOM + BMI160.
- Browser flashes sanitized firmware to actual board.
- User enters WiFi credentials after flash.
- Credentials travel only over Web Serial.
- Correct credentials produce connected status within defined timeout.
- Wrong credentials show retry state without reflash.
- Credentials survive tracker reboot.
- Custom IMU orientation and battery divider remain correct.
- Tracker connects to SlimeVR Server.
- UI passes keyboard, focus, contrast, reduced-motion, and 320px layout checks.
- README links to web flasher and manual recovery path.
- CI builds firmware, verifies release, and deploys only after successful checks.
- No known private credentials exist in deployed source or binary.
- Unknown serial device is rejected before any credential transmission.
- Malformed/oversized provisioning input is rejected without stack growth, NVS change, or reconnect attempt.
- Open network is clearly unsupported; WPA/WPA2 validation matches firmware.
- Flash cancel/failure and serial disconnect return to safe retry states.
- Reloaded page offers direct existing-firmware provisioning without another flash.
- Stale serial output cannot produce false success.
- Full-erase and non-erase effects on NVS/LittleFS are documented from physical tests.
- Human owner signs off recorded FT231XS hardware test evidence: date, board revision, browser version, firmware commit, result, and relevant sanitized logs/screenshots.

## 15. Execution Order for Lower-Capability Agent

Follow order exactly. Do not begin next phase if current phase checks fail.

### Phase 0: Safety and baseline

1. Confirm owner rotated exposed passwords.
2. Run `git status`, `git diff`, and inspect current branch.
3. Fetch remote and verify PR #1 is merged. Base new branch on remote default branch commit containing battery commit `eaff1fe` or its merged descendant. If `origin/main` lacks that change, stop and reconcile branch history without reset/force-push; do not drop battery-divider/orientation work.
4. Create branch `feat/web-firmware-installer` from verified base.
5. Do not modify unrelated user changes.
6. Record baseline firmware build result.

Exit condition: clean understanding of branch and successful baseline build, or documented existing build failure.

### Phase 1: Sanitize and harden firmware

1. Remove active hardcoded WiFi credentials.
2. Fix serial provisioning validation and ESP32 failed-credential retry behavior.
3. Preserve all hardware defines.
4. Build firmware.
5. Flash physical tracker manually.
6. Test `SET BWIFI` through serial monitor.
7. Confirm NVS persistence.

Exit condition: generic firmware can receive and retry WiFi credentials over serial.

Suggested commit:

```text
fix(firmware): harden WiFi provisioning
```

### Phase 2: Build static UI

1. Create semantic `site/index.html` structure.
2. Create design tokens and responsive layout in `site/styles.css`.
3. Implement state machine, validation, UTF-8 Base64, and serial parser in `site/app.js`.
4. Add pinned ESP Web Tools dependency and license note.
5. Add initial manifest placeholder consumed by packaging script.
6. Test locally without credentials in logs/storage.

Exit condition: UI states and serial provisioning work against already-flashed hardware.

Suggested commit:

```text
feat(web): add tracker installer interface
```

### Phase 3: Package firmware for web flashing

1. Implement preparation and verification scripts.
2. Capture exact PlatformIO addresses and flash parameters.
3. Merge required images into one full image at offset `0`.
4. Generate manifest and checksums.
5. Serve `dist/` locally over HTTP.
6. Flash actual board using local site.
7. Complete end-to-end WiFi setup.

Exit condition: blank/recoverable board flashes and connects from local static site.

Suggested commit:

```text
build(web): package ESP32 firmware artifacts
```

### Phase 4: CI and GitHub Pages

1. Add pinned GitHub Actions workflow.
2. Validate workflow on pull request.
3. Ensure Pages deploy job does not run on pull requests.
4. Enable `Settings -> Pages -> Source: GitHub Actions`.
5. Merge only after firmware/site checks pass.
6. Verify production URL and manifest binary downloads.

Exit condition: `main` deployment succeeds and hosted end-to-end hardware test passes.

Suggested commit:

```text
ci(pages): deploy web firmware installer
```

### Phase 5: Documentation and release

1. Update exactly root `README.md` and `FIRMWARE/README.md`.
2. Add version/checksum display.
3. Run full acceptance test.
4. Review `git diff` for credentials and unrelated changes.
5. Push branch.
6. Create pull request with test evidence and hosted preview limitations.
7. Merge after review and successful CI.
8. Test production Pages URL with real hardware.

Suggested commit:

```text
docs: add browser flashing guide
```

## 16. Pull Request Checklist

PR description must include:

- Problem solved.
- Supported hardware profile.
- Firmware source commit.
- Flash offsets and how they were verified.
- Security statement that no private WiFi credentials are embedded.
- Browser support matrix.
- Actual hardware test results.
- Screenshots at desktop and mobile widths.
- Accessibility checks.
- Recovery procedure tested.
- Pages URL after merge.

Before push/PR:

```powershell
git config user.email "jrjuarendra@gmail.com"
git status
git diff --check
git diff origin/main...HEAD
git log --oneline -10
```

Do not force-push, rewrite history, or merge directly without explicit owner request.

## 17. Future Upgrade, Not Version 1

After version 1 is stable, consider replacing custom `SET BWIFI` browser integration with Improv Serial firmware support. ESP Web Tools can then own flash and WiFi provisioning in one native dialog and support later `Change Wi-Fi` flow.

Add Improv only when:

- Current web flasher has stable hardware coverage.
- Protocol implementation has malformed-frame tests.
- Existing text serial commands remain compatible.
- Firmware size still fits OTA partition.

Do not add Improv dependency during first release merely for UI convenience.

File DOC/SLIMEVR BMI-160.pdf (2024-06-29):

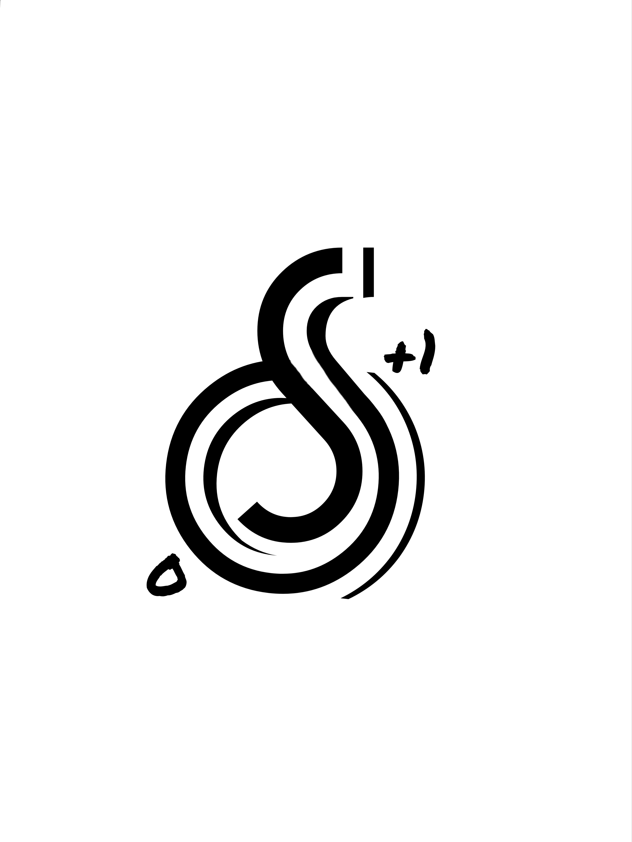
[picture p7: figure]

# POSITRON ELEKTRONIK SLIMEVR BMI-160

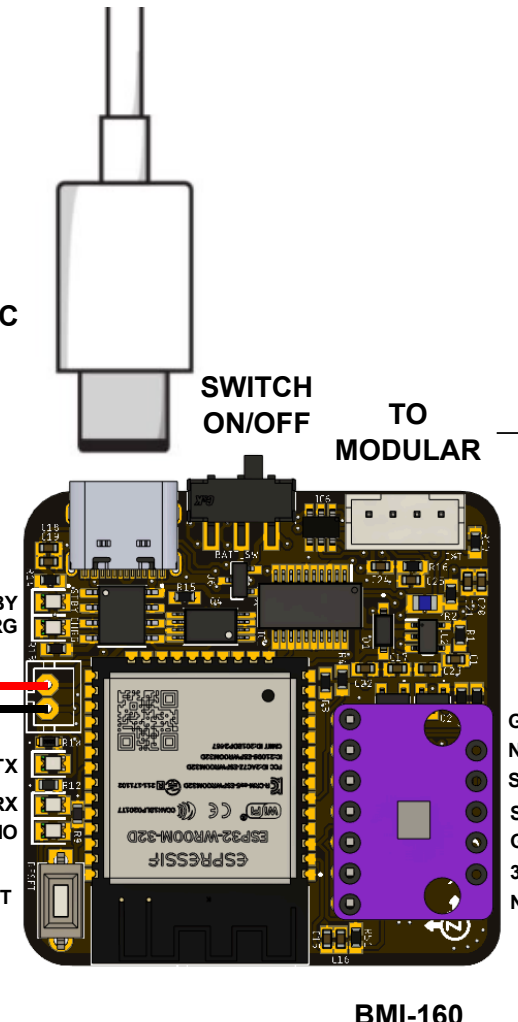
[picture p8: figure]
SWITCH; ON/OFF; MODULAR

## USB TYPE C

## LIPPO BATTERY

3.7V

## BMI-160 IMU ESP32

RESET

GND
NC
SDA / ESP32 IO21
SCL / ESP32 IO22
GND
3V3
NC

SDA / ESP32 IO21
SCL / ESP32 IO22

GND
3V3

LED IO

RX

TX

STBY
CHRG

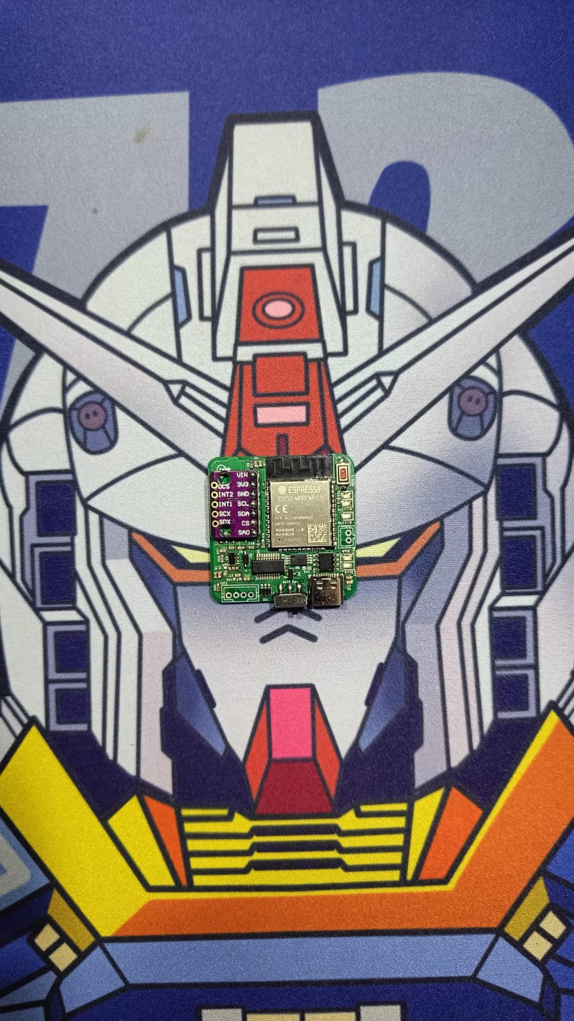
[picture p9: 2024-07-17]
DOC/slimeVR_pcb_1.jpeg

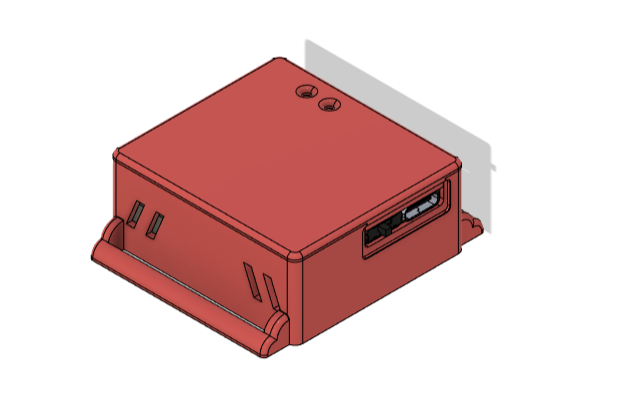
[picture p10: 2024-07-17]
DOC/slimeVR_case_3.png

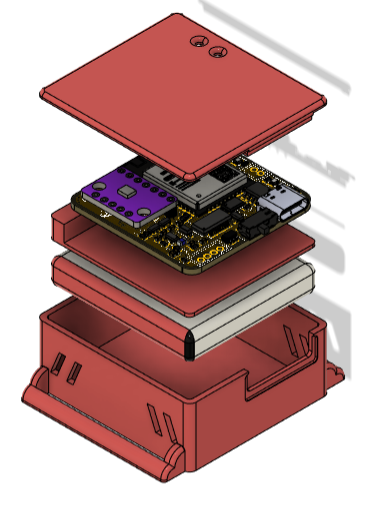
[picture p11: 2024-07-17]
DOC/slimeVR_case_5.png

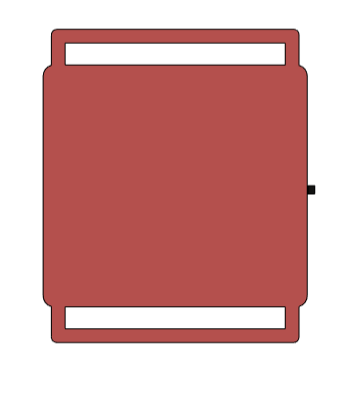
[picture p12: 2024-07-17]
DOC/slimeVR_case_4.png

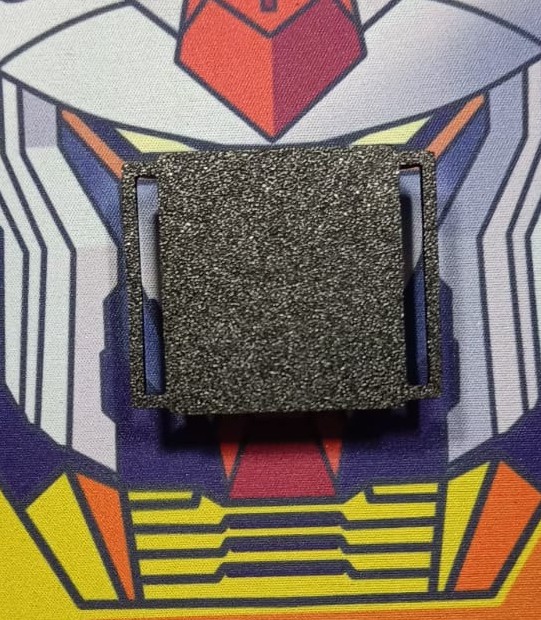
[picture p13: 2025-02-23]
DOC/slimeVR_real_4.jpeg

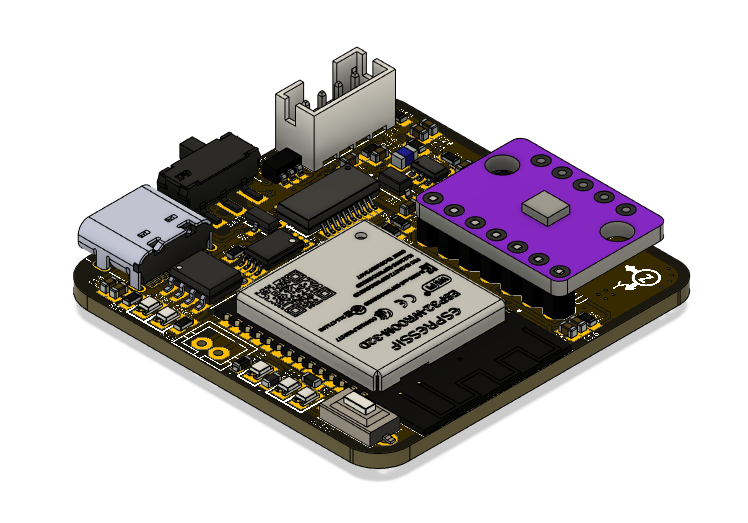
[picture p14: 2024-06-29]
DOC/slimeVR_1.png

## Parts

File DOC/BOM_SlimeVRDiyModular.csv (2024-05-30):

Qty | Value | Device | Package | Parts | Description | AVAILABILITY | BUILT_BY | CATEGORY | CHECK_PRICES | COPYRIGHT | DESCRIPTION | DIGIKEY_PARTNUMBER | DIGIKEY_PRICE-STOCK | HEIGHT | LCSC_PART_NUMBER | LCSC_PRICE-STOCK | MANUFACTURER_NAME | MANUFACTURER_PART_NUMBER | MF | MOUSER_PART_NUMBER | MOUSER_PRICE-STOCK | MP | PACKAGE | PART_STATUS | POPULARITY | PRICE | PURCHASE-URL | SERIES | SNAPEDA_LINK | VALUE | VENDOR
1 |  | JST-PH2 | JST-PH2 | P1
1 |  | JST-PH4 | JST-PH4 | EXT
1 |  | PINHD-1X7 | 1X07 | IMU | PIN HEADER |  |  |  |  |  |  |  |  |  |  |  |  |  |  |  |  |  |  |  | 0
1 | 1.2k | ESR03EZPJ102 | RESC1608X55N | R15 | Thick Film Resistors - SMD 0603 1Kohm 5% Anti Surge AEC-Q200 |  |  |  |  |  | Thick Film Resistors - SMD 0603 1Kohm 5% Anti Surge AEC-Q200 | RHM1.0KDCT-ND | https://www.digikey.com/product-detail/en/rohm-semiconductor/ESR03EZPJ102/RHM1-0KDCT-ND/1762924 | 0.55mm |  |  | ROHM Semiconductor | ESR03EZPJ102 |  | 755-ESR03EZPJ102 | https://www.mouser.co.uk/ProductDetail/ROHM-Semiconductor/ESR03EZPJ102?qs=DyUWGjl%252BcVvjMuV%252BzioV7Q%3D%3D |  |  |  |  |  |  |  |  | 1k
1 | 100 | ESR03EZPJ102 | RESC1608X55N | R16 | Thick Film Resistors - SMD 0603 1Kohm 5% Anti Surge AEC-Q200 |  |  |  |  |  | Thick Film Resistors - SMD 0603 1Kohm 5% Anti Surge AEC-Q200 | RHM1.0KDCT-ND | https://www.digikey.com/product-detail/en/rohm-semiconductor/ESR03EZPJ102/RHM1-0KDCT-ND/1762924 | 0.55mm |  |  | ROHM Semiconductor | ESR03EZPJ102 |  | 755-ESR03EZPJ102 | https://www.mouser.co.uk/ProductDetail/ROHM-Semiconductor/ESR03EZPJ102?qs=DyUWGjl%252BcVvjMuV%252BzioV7Q%3D%3D |  |  |  |  |  |  |  |  | 1k
8 | 100nf | 885012206071 | CAPC1608X87N | C1, C15, C17, C18, C19, C23, C24, C25 | Wurth Elektronik 0603 WCAP-CSGP 100nF Ceramic Multilayer Capacitor, 25 V dc, +125C, X7R Dielectric, +/-10% |  |  |  |  |  | Wurth Elektronik 0603 WCAP-CSGP 100nF Ceramic Multilayer Capacitor, 25 V dc, +125C, X7R Dielectric, +/-10% | 732-7989-1-ND | https://www.digikey.com/product-detail/en/w%C3%BCrth-elektronik/885012206071/732-7989-1-ND/5454616 | 0.87mm |  |  | Wurth Elektronik | 885012206071 |  | 710-885012206071 | https://www.mouser.co.uk/ProductDetail/Wurth-Elektronik/885012206071?qs=0KOYDY2FL2%2FEBQkuHgvarg%3D%3D |  |  |  |  |  |  |  |  | 100nf
5 | 10k | ESR03EZPJ103 | RESC1608X55N | R1, R3, R7, R8, R51 | Thick Film Resistors - SMD 0603 10Kohm 5% Anti Surge AEC-Q200 |  |  |  |  |  | Thick Film Resistors - SMD 0603 10Kohm 5% Anti Surge AEC-Q200 | RHM10KDCT-ND | https://www.digikey.com/product-detail/en/rohm-semiconductor/ESR03EZPJ103/RHM10KDCT-ND/1762925 | 0.55mm |  |  | ROHM Semiconductor | ESR03EZPJ103 |  | 755-ESR03EZPJ103 | https://www.mouser.com/Search/Refine.aspx?Keyword=755-ESR03EZPJ103 |  |  |  |  |  |  |  |  | 10k
2 | 10nf | 885012206089 | CAPC1608X87N | C16, C21 | Wurth Elektronik 0603 WCAP-CSGP 10nF Ceramic Multilayer Capacitor, 50 V dc, +125C, X7R Dielectric, +/-10% |  |  |  |  |  | Wurth Elektronik 0603 WCAP-CSGP 10nF Ceramic Multilayer Capacitor, 50 V dc, +125C, X7R Dielectric, +/-10% | 732-8007-1-ND | https://www.digikey.com/product-detail/en/w%C3%BCrth-elektronik/885012206089/732-8007-1-ND/5454634 | 0.87mm |  |  | Wurth Elektronik | 885012206089 |  | 710-885012206089 | https://www.mouser.co.uk/ProductDetail/Wurth-Elektronik/885012206089?qs=0KOYDY2FL28GvSbKh319Tw%3D%3D |  |  |  |  |  |  |  |  | 10nf
1 | 1825966-1 | 1825966-1 | SWDIP2_256X170P100 | RESET |  |  | EMA_UL_Team | Tactile Switches |  | Copyright (C) 2016 Accelerated Designs. All rights reserved | FSMCH=3.5 X 6.0 X 4.3 TACT SWITCH, HT |  |  |  |  |  |  | 1825966-1 |  |  |  |  |  | active |  |  |  | Unknown |  |  | TE Connectivity
1 | 1N5819HW-7 | 1N5819HW-7 | SOD3715X145N | D1 | 1N5819HW Series 40 V 1 A Surface Mount Schottky Barrier Rectifier - SOD-123 Check availability | In Stock |  |  | https://www.snapeda.com/parts/1N5819HW-7/Diodes+Inc./view-part/?ref=eda |  | Diode Schottky 40 V 1A Surface Mount SOD-123 |  |  |  |  |  |  |  | Diodes Inc. |  |  | 1N5819HW-7 | SOD-123 Fairchild Semiconductor |  |  | None | https://www.snapeda.com/api/url_track_click_mouser/?unipart_id=51510&manufacturer=Diodes Inc.&part_name=1N5819HW-7&search_term=1n5819 |  | https://www.snapeda.com/parts/1N5819HW-7/Diodes+Inc./view-part/?ref=snap
3 | 1k | ESR03EZPJ102 | RESC1608X55N | R13, R14, R17 | Thick Film Resistors - SMD 0603 1Kohm 5% Anti Surge AEC-Q200 |  |  |  |  |  | Thick Film Resistors - SMD 0603 1Kohm 5% Anti Surge AEC-Q200 | RHM1.0KDCT-ND | https://www.digikey.com/product-detail/en/rohm-semiconductor/ESR03EZPJ102/RHM1-0KDCT-ND/1762924 | 0.55mm |  |  | ROHM Semiconductor | ESR03EZPJ102 |  | 755-ESR03EZPJ102 | https://www.mouser.co.uk/ProductDetail/ROHM-Semiconductor/ESR03EZPJ102?qs=DyUWGjl%252BcVvjMuV%252BzioV7Q%3D%3D |  |  |  |  |  |  |  |  | 1k
1 | 1uF | CAP_CERAMIC0603 | 0603 | C14 | Ceramic Capacitors
2 | 1uf | 885012206071 | CAPC1608X87N | C20, C22 | Wurth Elektronik 0603 WCAP-CSGP 100nF Ceramic Multilayer Capacitor, 25 V dc, +125C, X7R Dielectric, +/-10% |  |  |  |  |  | Wurth Elektronik 0603 WCAP-CSGP 100nF Ceramic Multilayer Capacitor, 25 V dc, +125C, X7R Dielectric, +/-10% | 732-7989-1-ND | https://www.digikey.com/product-detail/en/w%C3%BCrth-elektronik/885012206071/732-7989-1-ND/5454616 | 0.87mm |  |  | Wurth Elektronik | 885012206071 |  | 710-885012206071 | https://www.mouser.co.uk/ProductDetail/Wurth-Elektronik/885012206071?qs=0KOYDY2FL2%2FEBQkuHgvarg%3D%3D |  |  |  |  |  |  |  |  | 100nf
3 | 330 | ERJ-H3EF3300V | ERJH3 | R9, R10, R12 | Power Rating 0.125W,Resistance 330 Ohm,LxW(EIA) 1.6 x 0.8 (EIA:0603) mm |  |  |  |  |  | Power Rating 0.125W,Resistance 330 Ohm,LxW(EIA) 1.6 x 0.8 (EIA:0603) mm |  |  | mm |  |  | Panasonic | ERJ-H3EF3300V |  | 667-ERJ-H3EF3300V | https://www.mouser.co.uk/ProductDetail/Panasonic/ERJ-H3EF3300V?qs=eP2BKZSCXI61roRLPi8W7w%3D%3D |  |  |  |  |  |  |  |  | 330
2 | 40k2 | ERJ-S03F4022V | RESC1608X55N | R2, R4 | Thick Film Resistors - SMD 0603 40.2Kohms 1% Anti-Sulfur |  |  |  |  |  | Thick Film Resistors - SMD 0603 40.2Kohms 1% Anti-Sulfur |  |  | 0.55mm |  |  | Panasonic | ERJ-S03F4022V |  | 667-ERJ-S03F4022V | https://www.mouser.com/Search/Refine.aspx?Keyword=667-ERJ-S03F4022V
1 | DW01A | DW01A | SOT23-6 | IC6 | Check availability | Not in stock |  |  | https://www.snapeda.com/parts/DW01A/Fortune+Semiconductor/view-part/?ref=eda |  | One Cell Lithium-ion/Polymer Battery Protection IC |  |  |  |  |  |  |  | Fortune Semiconductor |  |  | DW01A | SOT-23-6 Fortune Semiconductor |  |  | None |  |  | https://www.snapeda.com/parts/DW01A/Fortune+Semiconductor/view-part/?ref=snap
1 | ESP32-WROOM-32D | ESP32-WROOM-32D | MODULE_ESP32-WROOM-32D | ESP32 | Bluetooth, WiFi 802.11b/g/n, Bluetooth v4.2 + EDR, Class 1, 2 and 3 Transceiver Module 2.4GHz ~ 2.5GHz Integrated, Trace Surface Mount Check availability | In Stock |  |  |  |  | Bluetooth, WiFi 802.11b/g/n, Bluetooth v4.2 +EDR, Class 1, 2 and 3 Transceiver Module 2.4GHz ~ 2.5GHz Integrated |  |  |  |  |  |  |  | Espressif Systems |  |  | ESP32-WROOM-32D | Module Espressif Systems |  |  | None | https://pricing.snapeda.com/search/part/ESP32-WROOM-32D/?ref=eda
1 | FS8205A | FS8205A | SOP65P640X120-8N | Q4 | N/A Check availability | Not in stock |  |  | https://www.snapeda.com/parts/FS8205A/Fortune+Semiconductor/view-part/?ref=eda |  |  |  |  |  |  |  |  |  | Fortune Semiconductor |  |  | FS8205A | Package |  |  | None |  |  | https://www.snapeda.com/parts/FS8205A/Fortune+Semiconductor/view-part/?ref=snap
1 | FT231XS-R | FT231XS-R | SOP64P599X175-20N | IC1 | FTDI Chip FT231XS-R, Interface RS232, RS422, RS485, SIE, UART 3MBd, 5 V, 20-pin, SSOP |  |  |  |  |  | FTDI Chip FT231XS-R, Interface RS232, RS422, RS485, SIE, UART 3MBd, 5 V, 20-pin, SSOP |  |  | 1.753mm |  |  | FTDI Chip | FT231XS-R |  | 895-FT231XS-R | https://www.mouser.co.uk/ProductDetail/FTDI/FT231XS-R?qs=Gp1Yz1mis3WduRPsgrTbtg%3D%3D
5 | Green | 150080BS75000 | LEDC2012X80N | CHRG, LED, RX, STBY, TX | LED,Wurth Elektronik,150080BS75000 Wurth Elektronik 150080BS75000, WL-SMCW Series Blue LED, 470 nm 2012 (0805) Clear, Rectangle Lens SMD package |  |  |  |  |  | LED,Wurth Elektronik,150080BS75000 Wurth Elektronik 150080BS75000, WL-SMCW Series Blue LED, 470 nm 2012 (0805) Clear, Rectangle Lens SMD package |  |  | 0.8mm |  |  | Wurth Elektronik | 150080BS75000 |  | 710-150080BS75000 | https://www.mouser.co.uk/ProductDetail/Wurth-Elektronik/150080BS75000?qs=2kOmHSv6VfT2tBo3UPVqAQ%3D%3D |  |  |  |  |  |  |  |  | Green
1 | JS102011SAQN | JS102011SAQN | SW_JS102011SAQN | BATT_SW | <b> | In Stock |  |  | https://www.snapeda.com/parts/JS102011SAQN/C%2526K/view-part/?ref=eda |  | Slide Switch SPDT Surface Mount, Right Angle |  |  |  |  |  |  |  | C&K |  |  | JS102011SAQN | None |  |  | None | https://pricing.snapeda.com/search?q=JS102011SAQN&ref=eda |  | https://www.snapeda.com/parts/JS102011SAQN/C%2526K/view-part/?ref=snap
1 | M3406-ADJ | M3406-ADJ | SOT95P280X100-5N | IC2 | Step-down type SOT-23-5 DC-DC Converters ROHS |  |  |  |  |  | Step-down type SOT-23-5 DC-DC Converters ROHS |  |  | 1mm | C83224 | https://www.lcsc.com/product-detail/DC-DC-Converters_XI-AN-Aerosemi-Tech-M3406-ADJ_C83224.html | XI'AN Aerosemi Tech | M3406-ADJ
1 | MLF2012A2R2KT000 | MLF2012A2R2KT000 | INDC2012X105N | L1 | 2.2 H Shielded Multilayer Inductor 50 mA 500mOhm Max 0805 (2012 Metric) |  |  |  |  |  | 2.2 H Shielded Multilayer Inductor 50 mA 500mOhm Max 0805 (2012 Metric) |  |  | 1.05mm |  |  | TDK | MLF2012A2R2KT000 |  | 810-MLF2012A2R2KT000 | https://www.mouser.co.uk/ProductDetail/TDK/MLF2012A2R2KT000?qs=pLY5GE0xrmL3Y2Jw%2FEGjFg%3D%3D
2 | MMBT3904-TP | MMBT3904-TP | SI2305TP | Q1, Q2 | Bipolar Transistors - BJT 40V |  |  |  |  |  | Bipolar Transistors - BJT 40V |  |  | mm |  |  | Micro Commercial Components (MCC) | MMBT3904-TP |  | 833-MMBT3904-TP | https://www.mouser.co.uk/ProductDetail/Micro-Commercial-Components-MCC/MMBT3904-TP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
1 | SI2301BDS-T1-E3 | SI2301BDS-T1-E3 | SOT95P237X112-3N | U6 | MOSFET Check availability | In Stock |  |  | https://www.snapeda.com/parts/SI2301BDS-T1-E3/Vishay+Siliconix/view-part/?ref=eda |  | MOSFET,P-Ch,VDSS -20V,RDS(ON) 0.08Ohm,ID -2.2A,TO-236 (SOT-23),PD 0.7W,VGS +/-8V | Siliconix / Vishay SI2301BDS-T1-E3 |  |  |  |  |  |  |  | Vishay |  |  | SI2301BDS-T1-E3 | SOT-23-3 Vishay Siliconix |  |  | None | https://www.snapeda.com/api/url_track_click_mouser/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 |  | https://www.snapeda.com/parts/SI2301BDS-T1-E3/Vishay+Siliconix/view-part/?ref=snap
1 | TP4056 | TP4056 | SOP127P600X175-9N | U3 | Complete single cell Li-Ion battery with a constant current / constant voltage linear charger Check availability | Not in stock |  |  | https://www.snapeda.com/parts/TP4056/NanJing+Top+Power+ASIC+Corp./view-part/?ref=eda |  | Complete single cell Li-Ion battery with a constant current / constant voltage linear charger |  |  |  |  |  |  |  | NanJing Top Power ASIC Corp. |  |  | TP4056 | Package |  |  | None |  |  | https://www.snapeda.com/parts/TP4056/NanJing+Top+Power+ASIC+Corp./view-part/?ref=snap
1 | TYPE-C-31-M-12 | TYPE-C-31-M-12 | HRO_TYPE-C-31-M-12 | USB | Check availability | Not in stock |  |  | https://www.snapeda.com/parts/TYPE-C-31-M-12/HRO+Electronics+Co.%252C+Ltd./view-part/?ref=eda |  | USB Connectors 24 Receptacle 1 8.94*7.3mm RoHS |  |  |  |  |  |  |  | HRO Electronics Co., Ltd. |  |  | TYPE-C-31-M-12 | Package |  |  | None |  |  | https://www.snapeda.com/parts/TYPE-C-31-M-12/HRO+Electronics+Co.%252C+Ltd./view-part/?ref=snap

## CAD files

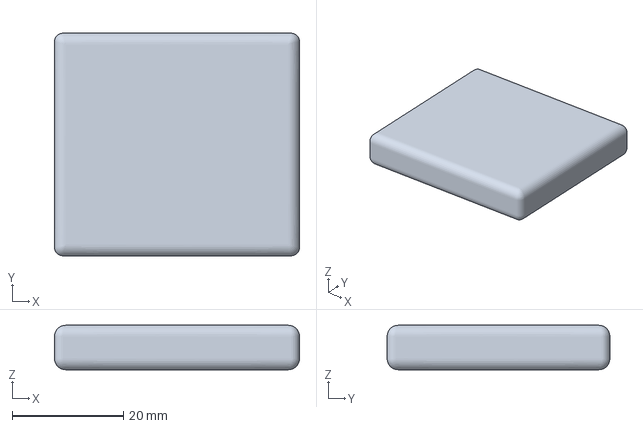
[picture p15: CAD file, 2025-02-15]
HARDWARE/case/top_case_slimeVR.3mf
44.0 x 40.0 x 8.00 mm

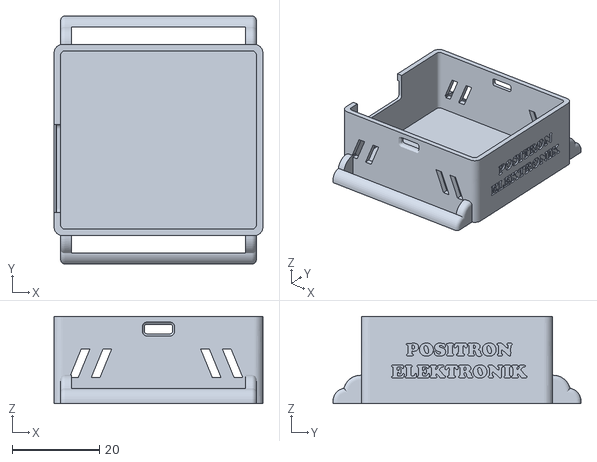
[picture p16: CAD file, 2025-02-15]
HARDWARE/case/bottom_case_slimeVR.stl
48.0 x 57.0 x 20.0

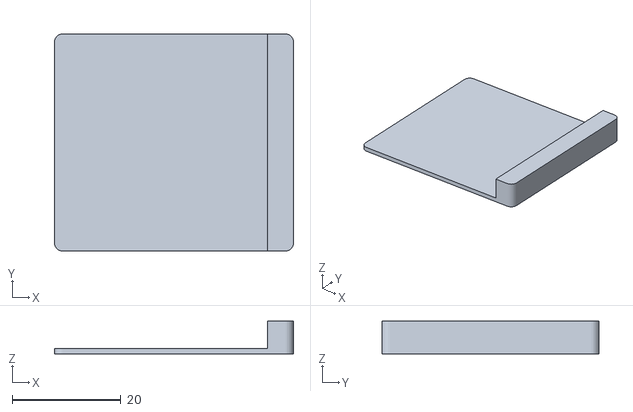
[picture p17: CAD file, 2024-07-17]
HARDWARE/case/spacer_battery_slimeVR.stl
44.0 x 40.0 x 6.00

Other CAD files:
HARDWARE/case/dumy_battery_slimeVR.stl
HARDWARE/case/top_case_slimeVR.stl

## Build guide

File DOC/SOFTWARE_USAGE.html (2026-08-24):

# 📘 Dokumentasi Software SlimeVR-BMI160

Panduan lengkap menggunakan Web Installer dan PlatformIO untuk tracker ESP32 + BMI160.

Web Installer PlatformIO ESP32

## 🔩 Hardware Overview

Berikut gambaran hardware SlimeVR-BMI160 tracker — komponen internal produk jadi dan layout PCB.

### Produk Jadi — Komponen Internal

Set tracker SlimeVR-BMI160 lengkap

Foto di atas menunjukkan set tracker SlimeVR-BMI160 yang sudah dirakit lengkap. Setiap unit tracker terdiri dari komponen-komponen berikut:

- Casing 3D-Print — Enclosure kompak hasil cetak 3D (FDM/resin) dengan desain snap-fit, dilengkapi lubang untuk port USB-C dan slide switch.
- PCB Utama — Board custom berukuran kompak yang memuat seluruh sirkuit elektronik tracker.
- ESP32-WROOM-32D — Mikrokontroler utama dengan WiFi 802.11 b/g/n dan Bluetooth 4.2, dual-core 240 MHz. Mengirim data sensor ke SlimeVR Server via WiFi.
- Modul BMI160 (IMU) — Sensor 6-axis (accelerometer + gyroscope) yang terpasang via header 7-pin, sehingga mudah diganti atau di-upgrade ke sensor lain.
- Baterai Li-Ion / LiPo — Sumber daya utama saat digunakan secara wireless, terhubung via konektor JST-PH 2-pin.
- Port USB Type-C — Digunakan untuk pengisian baterai dan flashing firmware.
- Slide Switch (On/Off) — Saklar daya di sisi casing untuk mematikan/menyalakan tracker.
- LED Indikator (5 buah) — LED Charging (biru, menyala saat mengisi), LED Standby (merah, menyala saat baterai penuh), LED ACK (merah, berkedip saat SlimeVR Server aktif), LED TX/RX (indikator komunikasi serial saat flashing).
- Elastic Strap — Tali elastis untuk memasang tracker ke bagian tubuh (paha, betis, dada, lengan, kaki).

Untuk full-body tracking, dibutuhkan 5–7 unit tracker tergantung titik tracking yang diinginkan (minimal: paha kiri-kanan, betis kiri-kanan, dan dada/hip).

### Layout PCB & Pinout

PCB layout dan pinout SlimeVR-BMI160

Gambar di atas menunjukkan layout PCB SlimeVR-BMI160 dengan penjelasan bagian-bagian utama:

- ESP32-WROOM-32D — Modul mikrokontroler di bagian tengah PCB, menempati area terbesar. Antena WiFi internal berada di ujung modul (tidak boleh tertutup ground plane).
- FT231XS-R (USB-to-UART) — IC konverter USB ke serial di dekat konektor USB-C. Memungkinkan flashing firmware dan serial monitoring via USB.
- TP4056 (Battery Charger) — IC charger baterai Li-Ion dengan constant current/constant voltage, terletak di dekat konektor USB-C dan konektor baterai.
- DW01A + FS8205A (Battery Protection) — Rangkaian proteksi baterai terhadap over-charge, over-discharge, overcurrent, dan short circuit.
- M3406-ADJ (Voltage Regulator) — DC-DC step-down converter yang mengubah tegangan baterai (3.7–4.2V) menjadi 3.3V stabil untuk ESP32 dan sensor.
- Konektor USB Type-C — Port input di tepi PCB untuk pengisian daya dan komunikasi serial.
- Header IMU 7-pin — Socket pin header untuk modul sensor BMI160. Desain modular — sensor bisa dilepas/diganti tanpa solder ulang.
- Konektor Baterai JST-PH 2-pin (P1) — Port untuk menghubungkan baterai Li-Ion/LiPo.
- Konektor Ekstensi JST-PH 4-pin (EXT) — Port I2C tambahan untuk menghubungkan sensor eksternal atau modul ekspansi.
- Slide Switch (BATT_SW) — Saklar on/off yang memutus jalur daya baterai.
- Tombol Reset — Tombol taktil untuk me-reset ESP32 secara manual.
- LED Indikator — 5 LED SMD tersebar di PCB: CHRG (charging), STBY (standby/penuh), LED (ACK), TX, dan RX.
- Transistor Auto-Reset (Q1, Q2) — Rangkaian MMBT3904 untuk auto-reset ESP32 saat flashing via USB, sehingga tidak perlu tekan tombol manual.
- Dioda Schottky 1N5819HW (D1) — Proteksi reverse polarity pada jalur daya USB.

## 🎯 Pendahuluan

Tracker SlimeVR-BMI160 adalah perangkat full-body tracking DIY berbasis ESP32 dan sensor BMI160. Dokumentasi ini memandu Anda melalui dua metode utama:

- 🌐 Web Installer — cara termudah, tanpa instalasi software (direkomendasikan)
- ⚙️ Manual (PlatformIO) — untuk pengembang yang ingin mengompilasi sendiri

## 📸 Panduan Bergambar Web Installer

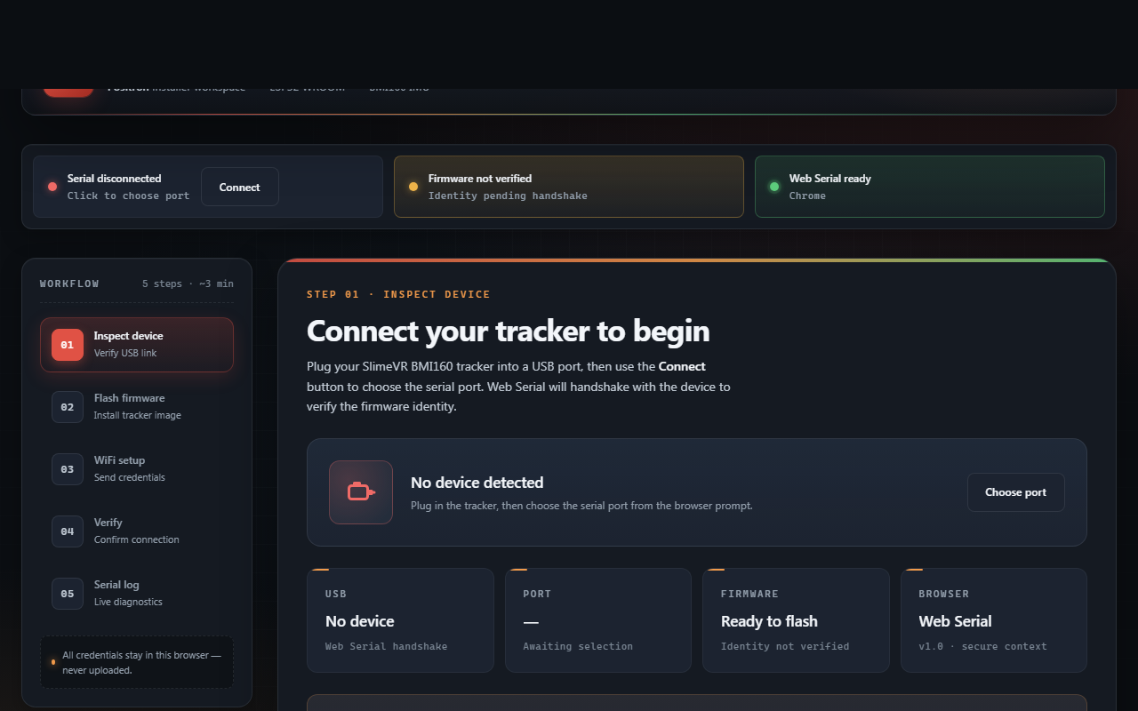
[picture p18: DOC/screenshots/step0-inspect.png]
Halaman utama
Langkah 1: Buka Halaman Web Installer 

Buka SlimeVR BMI160 Web Installer (https://juarendra.github.io/SlimeVR-BMI160/) di Chrome/Edge.

Langkah 2: Hubungkan Tracker & Connect Tombol Connect

1. Colokkan tracker via USB (pastikan kabel data).
2. Klik tombol Connect (pojok kiri atas).
3. Pilih port serial yang muncul (biasanya "USB Serial Port" atau COMx).

Langkah 3: Verifikasi Koneksi Status terhubung

Jika berhasil: status "Serial connected" berwarna hijau dan "Firmware verified" (jika firmware sudah ada).

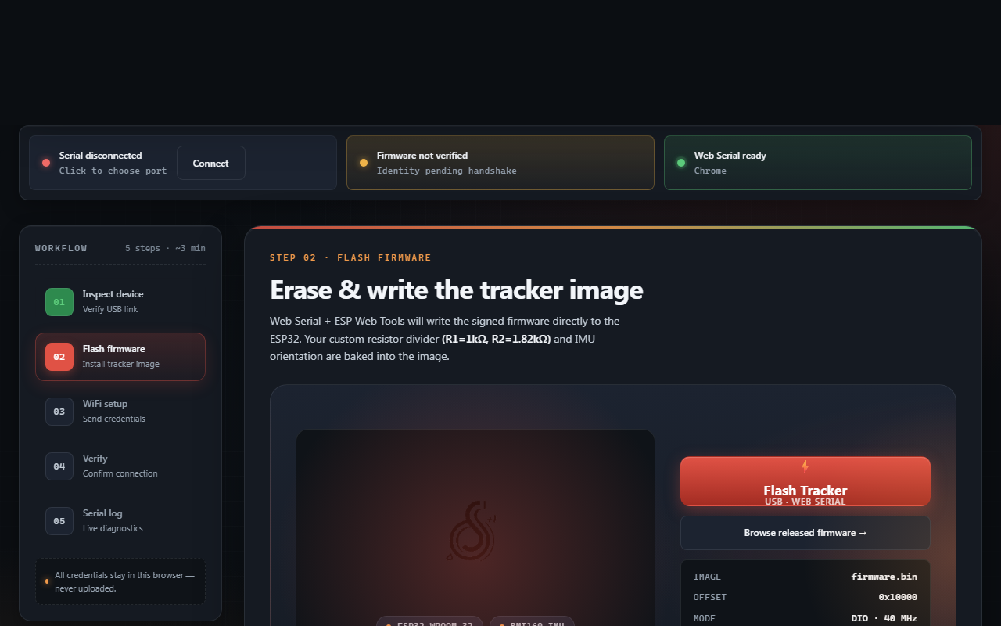
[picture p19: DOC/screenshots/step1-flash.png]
Tombol Flash Tracker
Langkah 4: Flash Firmware 

1. Pindah ke step 2 (klik "02 Flash firmware" di sidebar).
2. Klik tombol Flash Tracker.
3. Konfirmasi port dan tunggu hingga selesai (jangan cabut kabel!).

⏱️ Proses flashing berlangsung ±10 detik. Tracker reboot otomatis.

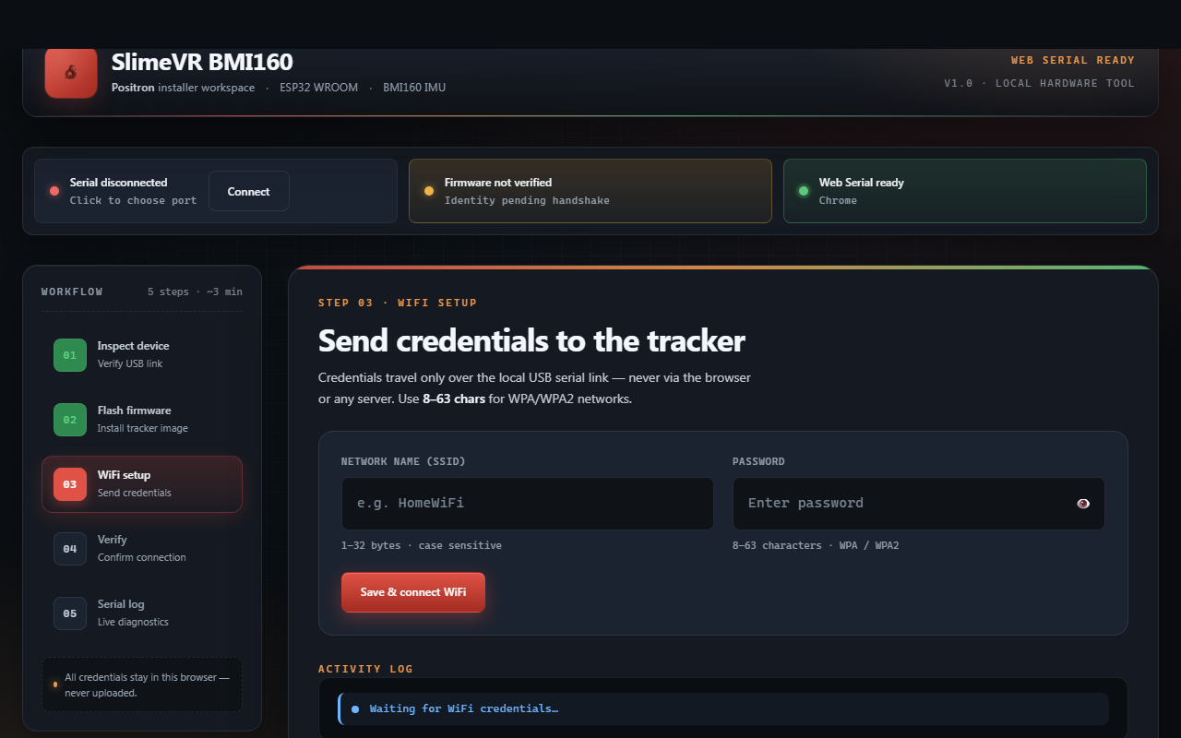
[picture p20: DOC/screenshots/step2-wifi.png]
Form WiFi
Langkah 5: Konfigurasi WiFi 

1. Pindah ke step 3.
2. Masukkan SSID dan Password WiFi Anda.
3. Klik Save & connect WiFi.
4. Tunggu hingga muncul "Connected" dan alamat IP.

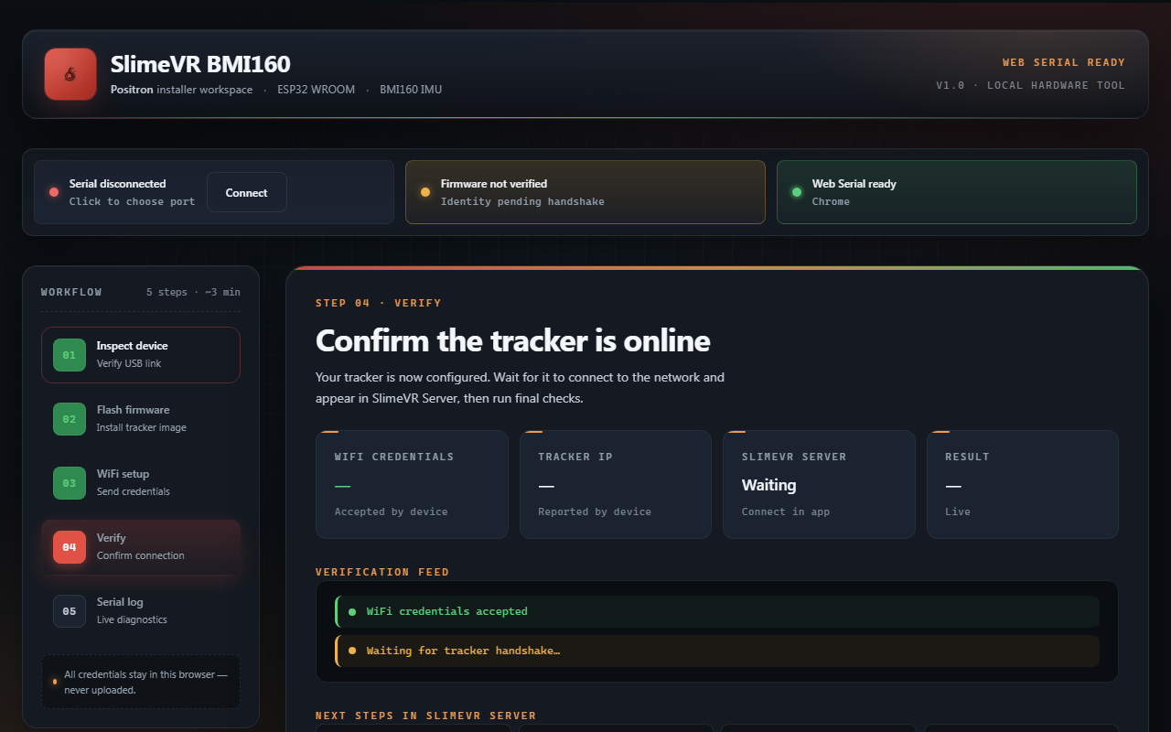
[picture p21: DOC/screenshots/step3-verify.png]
Tracker di server
Langkah 6: Verifikasi di SlimeVR Server 

Buka SlimeVR Server di PC — tracker akan muncul otomatis (pastikan satu jaringan).

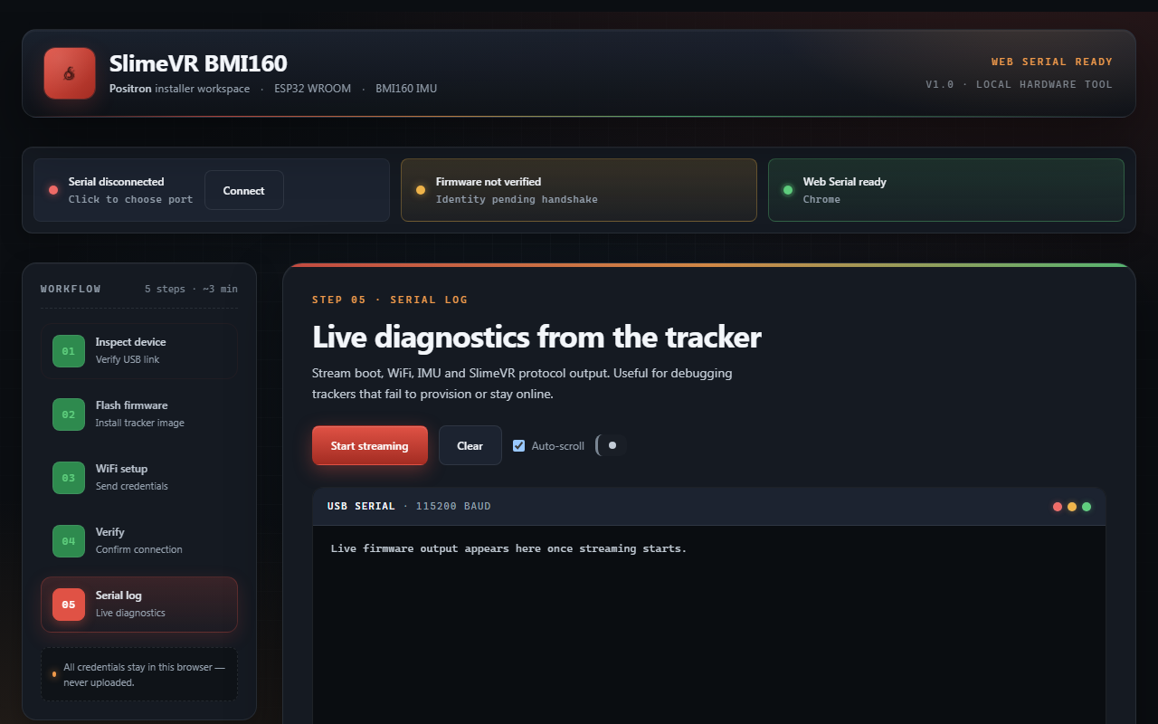
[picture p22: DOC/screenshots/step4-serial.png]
Serial log
Langkah 7: Serial Log (Debugging) 

Gunakan step 5 untuk melihat output real-time dari tracker (boot, WiFi, IMU, koneksi server).

## ⚙️ Metode Manual (PlatformIO)

### Prasyarat

- VS Code + ekstensi PlatformIO IDE
- Kabel USB data
- Tracker SlimeVR-BMI160 terhubung

### Langkah-langkah

1. Clone Repositori

git clone https://github.com/juarendra/SlimeVR-BMI160.git
cd SlimeVR-BMI160
2. Buka Proyek Firmware Buka folder FIRMWARE/SlimeVR-Tracker-ESP-0.4.0/ di VS Code. PlatformIO akan menginstal dependensi otomatis.
3. Konfigurasi WiFi (Hardcode) Buka platformio.ini, tambahkan di [env:esp32dev]:

build_flags =
    -DWIFI_SSID='"NAMA_WIFI_ANDA"'
    -DWIFI_PASSWORD='"PASSWORD_WIFI_ANDA"'
4. Erase Flash (Opsional)

pio run --target erase
5. Upload Firmware Klik tombol Upload (panah kanan) di toolbar PlatformIO. Tunggu hingga "SUCCESS".
6. Monitor Serial Klik ikon Serial Monitor (colokan), pastikan baud rate 115200.

### Output Serial yang Diharapkan

[20:13:30] [INFO] [main] Starting SlimeVR tracker...
[20:13:31] [INFO] [WIFI] Connecting to "NAMA_WIFI_ANDA"
[20:13:34] [INFO] [WIFI] WiFi connected. IP: 192.168.1.10
[20:13:34] [INFO] [I2C] Found BMI160 at address 0x68
[20:13:35] [INFO] [SERVER] Connected to server!
[20:13:36] [INFO] [OUTPUT:0] Sensor 0 reporting: ...

## 🔧 Perintah Serial untuk Provisioning (Advanced)

- GET INFO — tampilkan informasi perangkat.
- SET BWIFI <base64_ssid> <base64_pass> — kirim kredensial WiFi. Respon:
  - [WIFI-PROVISION] ACCEPTED
  - [WIFI-PROVISION] CONNECTED <IP>
  - [WIFI-PROVISION] FAILED <reason>

## 🐛 Troubleshooting Lanjutan

Masalah | Solusi
Sensor tidak terdeteksi | Periksa koneksi I2C, pastikan header BMI160 terpasang. Coba i2cscan.
WiFi gagal konek | Pastikan password benar, gunakan jaringan 2.4 GHz.
Tracker tidak muncul di server | Pastikan server berjalan dan firewall tidak memblokir.
Flashing manual gagal | Periksa driver USB, coba port lain, restart VS Code.

## 📚 Sumber Daya Tambahan

- SlimeVR Official (https://www.slimevr.dev/)
- GitHub Repo (https://github.com/juarendra/SlimeVR-BMI160)
- README Utama

Dokumentasi terakhir diperbarui: Agustus 2026

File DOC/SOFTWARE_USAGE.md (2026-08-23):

# Dokumentasi Penggunaan Software SlimeVR-BMI160

## 🎯 Pendahuluan

Tracker SlimeVR-BMI160 adalah perangkat full-body tracking DIY berbasis ESP32 dan sensor BMI160. Dokumentasi ini memandu Anda melalui dua metode utama:

- **🌐 Web Installer** — cara termudah, tanpa instalasi software (direkomendasikan)
- **⚙️ Manual (PlatformIO)** — untuk pengembang yang ingin mengompilasi sendiri

---

## 📸 Panduan Bergambar Web Installer

### Langkah 1: Buka Halaman Web Installer

Halaman utama Web Installer

Buka [SlimeVR BMI160 Web Installer](https://juarendra.github.io/SlimeVR-BMI160/) di Chrome/Edge.

### Langkah 2: Hubungkan Tracker & Connect

Tombol Connect

1. Colokkan tracker via USB (pastikan kabel data).
2. Klik tombol **Connect** (pojok kiri atas).
3. Pilih port serial yang muncul (biasanya "USB Serial Port" atau COMx).

### Langkah 3: Verifikasi Koneksi

Status terhubung

Jika berhasil:
- Status "Serial connected" berwarna hijau.
- "Firmware verified" (jika firmware sudah ada).

### Langkah 4: Flash Firmware

Tombol Flash Tracker

1. Pindah ke step 2 (klik "02 Flash firmware" di sidebar).
2. Klik tombol **Flash Tracker**.
3. Konfirmasi port dan tunggu hingga selesai (jangan cabut kabel!).

**Proses flashing berlangsung ±10 detik.** Setelah selesai, tracker reboot otomatis.

### Langkah 5: Konfigurasi WiFi

Form WiFi

1. Pindah ke step 3.
2. Masukkan **SSID** dan **Password** WiFi Anda.
3. Klik **Save & connect WiFi**.
4. Tunggu beberapa detik hingga muncul "Connected" dan alamat IP.

### Langkah 6: Verifikasi di SlimeVR Server

Tracker muncul di server

- Buka SlimeVR Server di PC.
- Tracker akan muncul otomatis (pastikan satu jaringan).

### Langkah 7: Serial Log (Debugging)

Serial log

Gunakan step 5 untuk melihat output real-time dari tracker (boot, WiFi, IMU).

---

## ⚙️ Metode Manual (PlatformIO)

### Prasyarat
- VS Code + PlatformIO IDE
- Kabel USB data

### Langkah-langkah

#### 1. Clone Repositori
```bash
git clone https://github.com/juarendra/SlimeVR-BMI160.git
cd SlimeVR-BMI160
```

#### 2. Buka Proyek Firmware
Buka folder `FIRMWARE/SlimeVR-Tracker-ESP-0.4.0/` di VS Code. PlatformIO akan menginstal dependensi otomatis.

#### 3. Konfigurasi WiFi (Hardcode)
Buka `platformio.ini`, tambahkan di `[env:esp32dev]`:
```ini
build_flags =
    -DWIFI_SSID='"NAMA_WIFI_ANDA"'
    -DWIFI_PASSWORD='"PASSWORD_WIFI_ANDA"'
```

#### 4. Erase Flash (Opsional)
```bash
pio run --target erase
```

#### 5. Upload Firmware
Klik tombol **Upload** (panah kanan) di toolbar PlatformIO. Tunggu hingga "SUCCESS".

#### 6. Monitor Serial
Klik ikon **Serial Monitor** (colokan), pastikan baud rate 115200.

### Output Serial yang Diharapkan
```
[20:13:30] [INFO] [main] Starting SlimeVR tracker...
[20:13:31] [INFO] [WIFI] Connecting to "NAMA_WIFI_ANDA"
[20:13:34] [INFO] [WIFI] WiFi connected. IP: 192.168.1.10
[20:13:34] [INFO] [I2C] Found BMI160 at address 0x68
[20:13:35] [INFO] [SERVER] Connected to server!
[20:13:36] [INFO] [OUTPUT:0] Sensor 0 reporting: ...
```

---

## 🔧 Perintah Serial untuk Provisioning (Advanced)

Firmware mendukung perintah serial berikut:

- `GET INFO` — tampilkan informasi perangkat.
- `SET BWIFI <base64_ssid> <base64_pass>` — kirim kredensial WiFi. Respon:
  - `[WIFI-PROVISION] ACCEPTED`
  - `[WIFI-PROVISION] CONNECTED <IP>`
  - `[WIFI-PROVISION] FAILED <reason>`

Perintah ini digunakan oleh Web Installer.

---

## 🐛 Troubleshooting Lanjutan

| Masalah | Solusi |
|---|---|
| **Sensor tidak terdeteksi** | Periksa koneksi I2C, pastikan header BMI160 terpasang. Coba `i2cscan`. |
| **WiFi gagal konek** | Pastikan password benar, gunakan jaringan 2.4 GHz. |
| **Tracker tidak muncul di server** | Pastikan server berjalan dan firewall tidak memblokir. |
| **Flashing manual gagal** | Periksa driver USB, coba port lain, restart VS Code. |

---

## 📚 Sumber Daya Tambahan

- [SlimeVR Official](https://www.slimevr.dev/)
- [GitHub Repo](https://github.com/juarendra/SlimeVR-BMI160)
- [README Utama](../README.md)

---

*Dokumentasi terakhir diperbarui: Agustus 2026*

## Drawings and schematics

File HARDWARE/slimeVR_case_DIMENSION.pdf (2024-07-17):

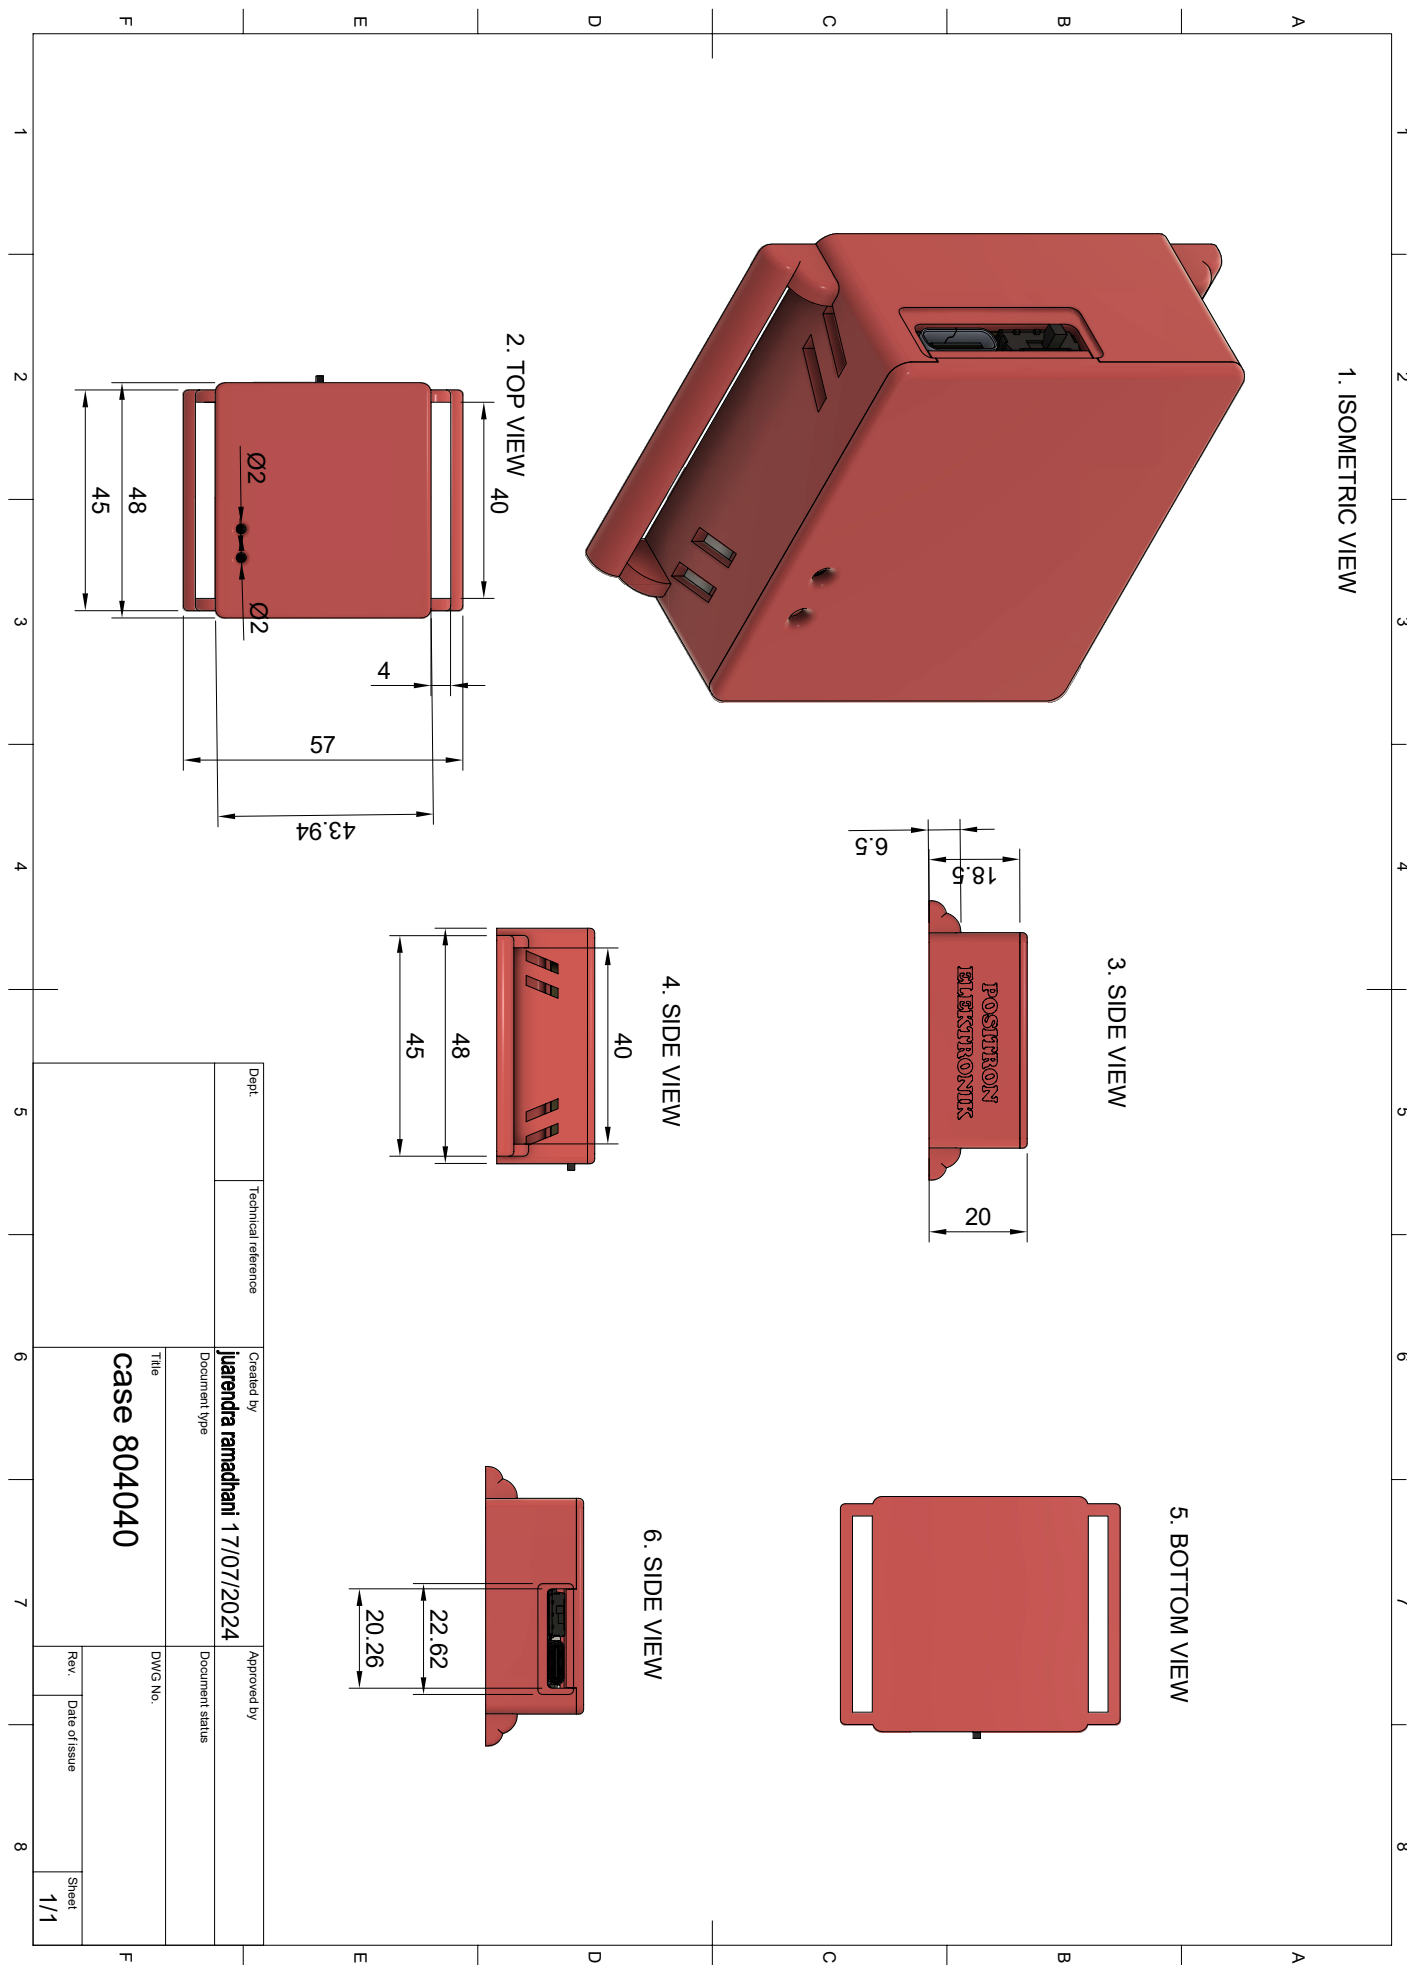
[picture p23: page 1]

1 A 2 3 4 5 6 7 8 1 2 3 4 5 6 7 8 FEDCB FEDCBA Dept. Technical reference Created by Approved by Title DWG No. Document type Document status Rev. Date of issue Sheet 17/07/2024 1/1 case 804040 1. ISOMETRIC VIEW 2. TOP VIEW 3. SIDE VIEW 4. SIDE VIEW 5. BOTTOM VIEW 6. SIDE VIEW 40 4

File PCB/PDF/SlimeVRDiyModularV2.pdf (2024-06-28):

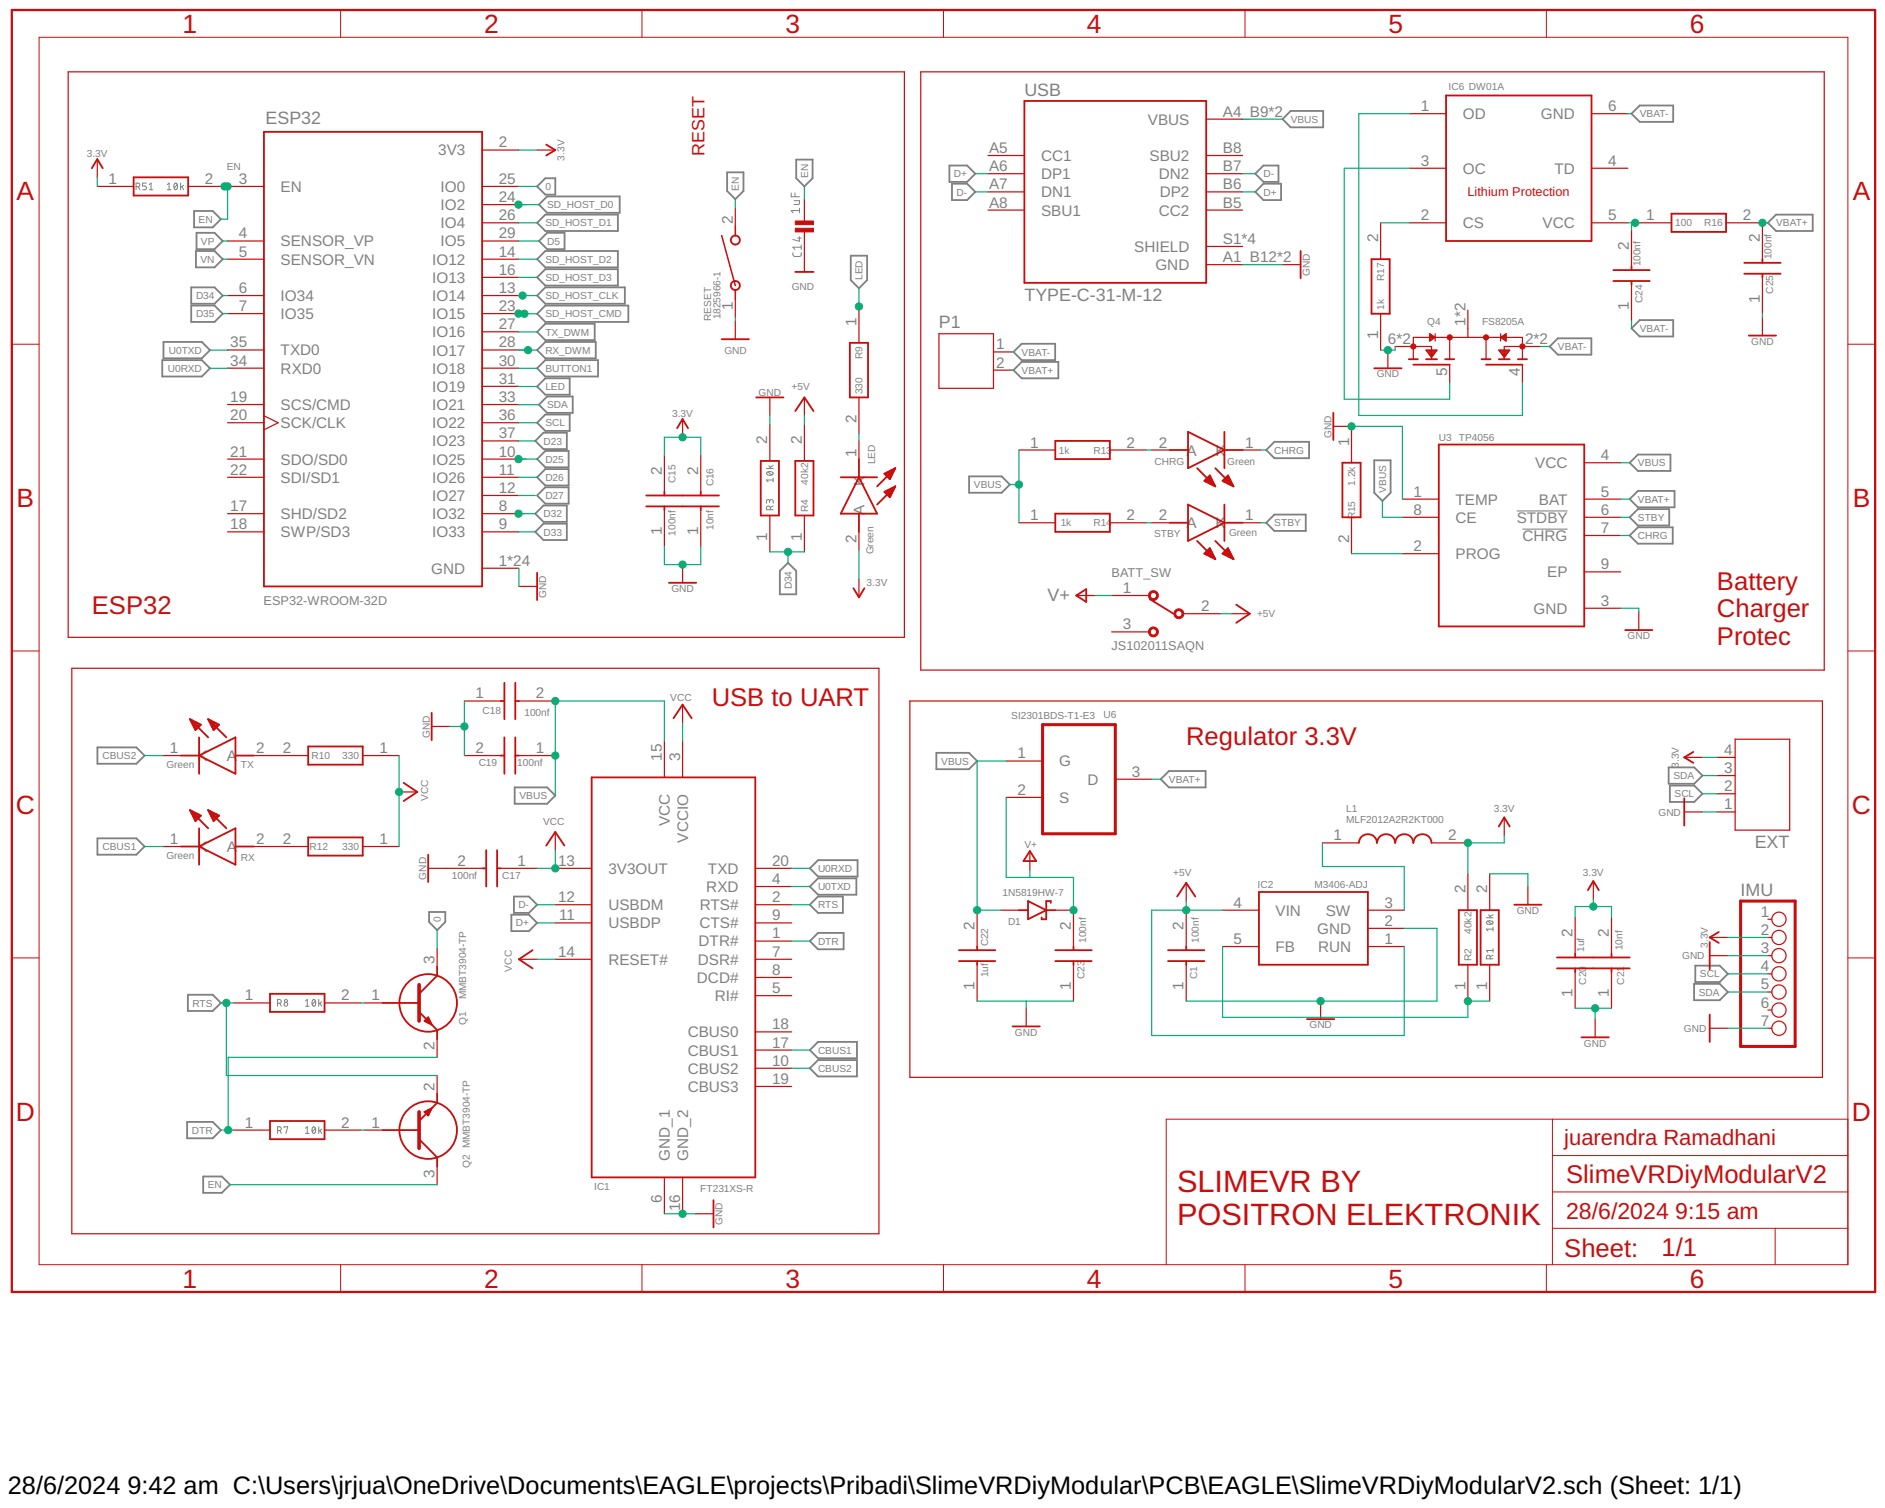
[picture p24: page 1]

28/6/2024 9:42 am C:\Users\jrjua\OneDrive\Documents\EAGLE\projects\Pribadi\SlimeVRDiyModular\PCB\EAGLE\SlimeVRDiyModularV2.sch (Sheet: 1/1)

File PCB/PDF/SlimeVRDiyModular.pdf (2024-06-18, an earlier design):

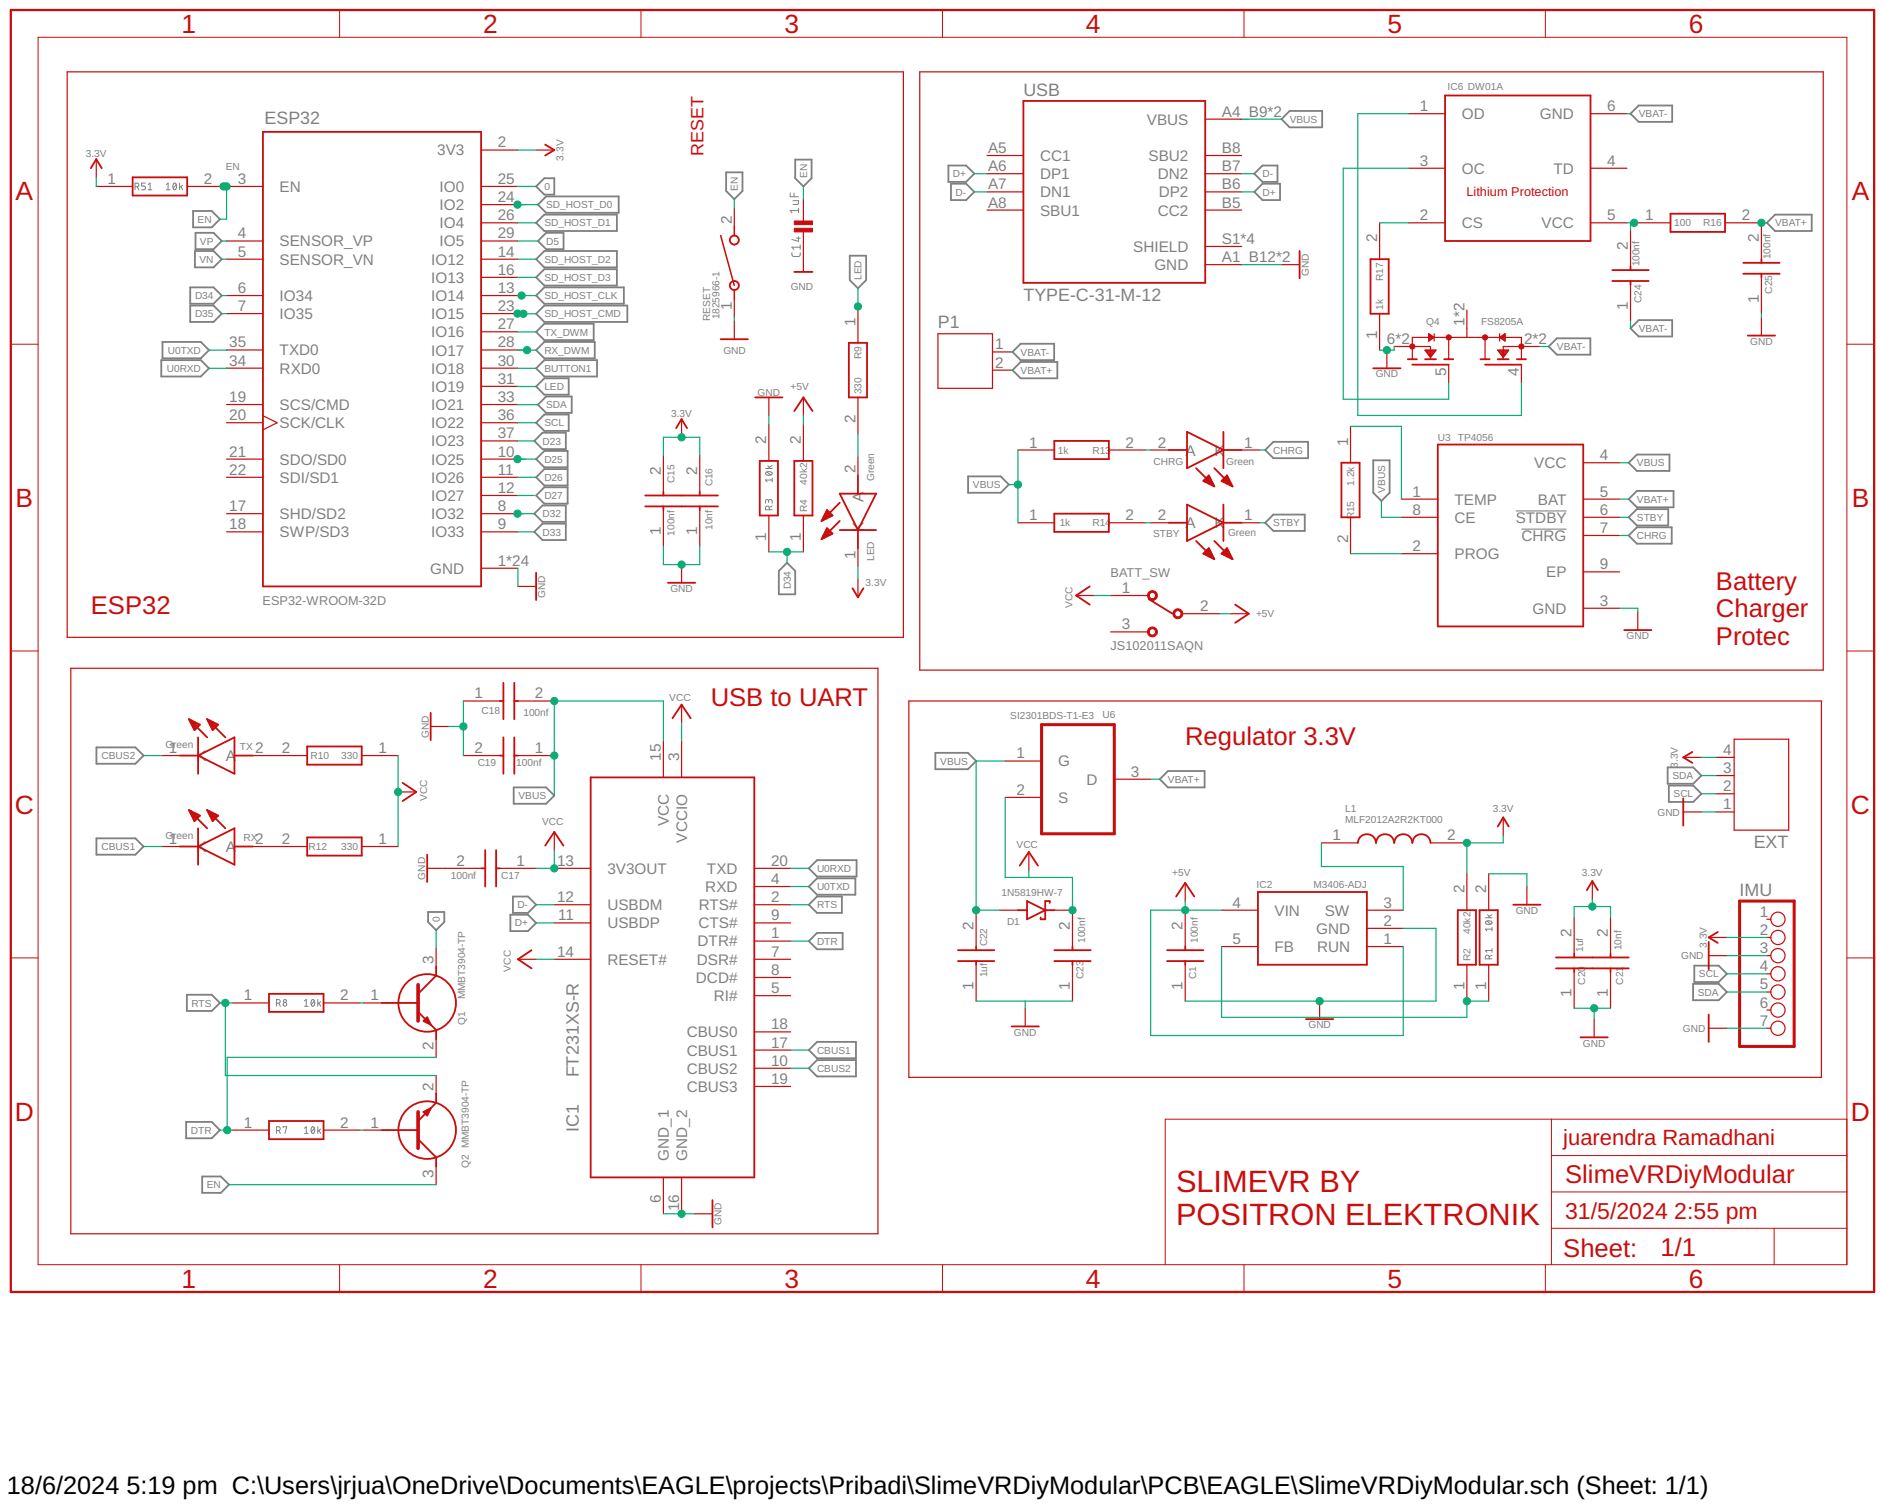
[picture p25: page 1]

18/6/2024 5:19 pm C:\Users\jrjua\OneDrive\Documents\EAGLE\projects\Pribadi\SlimeVRDiyModular\PCB\EAGLE\SlimeVRDiyModular.sch (Sheet: 1/1)

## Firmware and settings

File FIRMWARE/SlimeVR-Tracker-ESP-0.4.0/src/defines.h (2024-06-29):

/*
    SlimeVR Code is placed under the MIT license
    Copyright (c) 2021 Eiren Rain

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
    THE SOFTWARE IS PROVIDED "AS IS", WITHOUT WARRANTY OF ANY KIND, EXPRESS OR
    IMPLIED, INCLUDING BUT NOT LIMITED TO THE WARRANTIES OF MERCHANTABILITY,
    FITNESS FOR A PARTICULAR PURPOSE AND NONINFRINGEMENT. IN NO EVENT SHALL THE
    AUTHORS OR COPYRIGHT HOLDERS BE LIABLE FOR ANY CLAIM, DAMAGES OR OTHER
    LIABILITY, WHETHER IN AN ACTION OF CONTRACT, TORT OR OTHERWISE, ARISING FROM,
    OUT OF OR IN CONNECTION WITH THE SOFTWARE OR THE USE OR OTHER DEALINGS IN
    THE SOFTWARE.
*/
// ================================================
// See docs for configuration options and examples:
// https://docs.slimevr.dev/firmware/configuring-project.html#2-configuring-definesh
// ================================================

// Set parameters of IMU and board used
#define IMU IMU_BMI160
#define SECOND_IMU IMU
#define BOARD BOARD_WROOM32
#define IMU_ROTATION DEG_0
#define SECOND_IMU_ROTATION DEG_270

#define PRIMARY_IMU_OPTIONAL false
#define SECONDARY_IMU_OPTIONAL true

#define MAX_IMU_COUNT 1

// Axis mapping example
/*
#include "sensors/axisremap.h"
#define BMI160_QMC_REMAP AXIS_REMAP_BUILD(AXIS_REMAP_USE_Y, AXIS_REMAP_USE_XN, AXIS_REMAP_USE_Z, \
                                       AXIS_REMAP_USE_YN, AXIS_REMAP_USE_X, AXIS_REMAP_USE_Z)

IMU_DESC_ENTRY(IMU_BMP160, PRIMARY_IMU_ADDRESS_ONE, IMU_ROTATION, PIN_IMU_SCL, PIN_IMU_SDA, BMI160_QMC_REMAP) \
*/

#ifndef IMU_DESC_LIST
#define IMU_DESC_LIST \
        IMU_DESC_ENTRY(IMU,        PRIMARY_IMU_ADDRESS_ONE,   IMU_ROTATION,        PIN_IMU_SCL, PIN_IMU_SDA, PRIMARY_IMU_OPTIONAL,   PIN_IMU_INT) \
        IMU_DESC_ENTRY(SECOND_IMU, SECONDARY_IMU_ADDRESS_TWO, SECOND_IMU_ROTATION, PIN_IMU_SCL, PIN_IMU_SDA, SECONDARY_IMU_OPTIONAL, PIN_IMU_INT_2)
#endif

// Battery monitoring options (comment to disable):
//   BAT_EXTERNAL for ADC pin, 
//   BAT_INTERNAL for internal - can detect only low battery, 
//   BAT_MCP3021 for external ADC connected over I2C
#define BATTERY_MONITOR BAT_EXTERNAL

// BAT_EXTERNAL definition override
// D1 Mini boards with ESP8266 have internal resistors. For these boards you only have to adjust BATTERY_SHIELD_RESISTANCE.
// For other boards you can now adjust the other resistor values.
// The diagram looks like this:
//   (Battery)--- [BATTERY_SHIELD_RESISTANCE] ---(INPUT_BOARD)---  [BATTERY_SHIELD_R2] ---(ESP32_INPUT)--- [BATTERY_SHIELD_R1] --- (GND)
// #define BATTERY_SHIELD_RESISTANCE 180 //130k BatteryShield, 180k SlimeVR or fill in external resistor value in kOhm
#define BATTERY_SHIELD_R1 10 // Board voltage divider resistor Ain to GND in kOhm
#define BATTERY_SHIELD_R2 40.2 // Board voltage divider resistor Ain to INPUT_BOARD in kOhm

// LED configuration:
// Configuration Priority 1 = Highest:
// 1. LED_PIN
// 2. LED_BUILTIN
//
//   LED_PIN
//     - Number or Symbol (D1,..) of the Output
//     - To turn off the LED, set LED_PIN to LED_OFF
//   LED_INVERTED 
//     - false for output 3.3V on high
//     - true for pull down to GND on high
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

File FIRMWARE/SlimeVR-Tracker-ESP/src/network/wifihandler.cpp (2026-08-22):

/*
	SlimeVR Code is placed under the MIT license
	Copyright (c) 2021 Eiren Rain & SlimeVR contributors

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
	THE SOFTWARE IS PROVIDED "AS IS", WITHOUT WARRANTY OF ANY KIND, EXPRESS OR
	IMPLIED, INCLUDING BUT NOT LIMITED TO THE WARRANTIES OF MERCHANTABILITY,
	FITNESS FOR A PARTICULAR PURPOSE AND NONINFRINGEMENT. IN NO EVENT SHALL THE
	AUTHORS OR COPYRIGHT HOLDERS BE LIABLE FOR ANY CLAIM, DAMAGES OR OTHER
	LIABILITY, WHETHER IN AN ACTION OF CONTRACT, TORT OR OTHERWISE, ARISING FROM,
	OUT OF OR IN CONNECTION WITH THE SOFTWARE OR THE USE OR OTHER DEALINGS IN
	THE SOFTWARE.
*/
#include "GlobalVars.h"
#include "globals.h"
#include "logging/Logger.h"
#if !ESP8266
#include "esp_wifi.h"
#endif

unsigned long lastWifiReportTime = 0;
unsigned long wifiConnectionTimeout = millis();
bool isWifiConnected = false;
uint8_t wifiState = SLIME_WIFI_NOT_SETUP;
bool hadWifi = false;
unsigned long last_rssi_sample = 0;

// TODO: Cleanup with proper classes
SlimeVR::Logging::Logger wifiHandlerLogger("WiFiHandler");

void reportWifiError() {
	if (lastWifiReportTime + 1000 < millis()) {
		lastWifiReportTime = millis();
		Serial.print(".");
	}
}

void sendProvisionFailure(const char* error) {
	Serial.printf("[WIFI-PROVISION] FAILED %s\n", error);
}

void setStaticIPIfDefined() {
#ifdef WIFI_USE_STATICIP
	const IPAddress ip(WIFI_STATIC_IP);
	const IPAddress gateway(WIFI_STATIC_GATEWAY);
	const IPAddress subnet(WIFI_STATIC_SUBNET);
	WiFi.config(ip, gateway, subnet);
#endif
}

bool WiFiNetwork::isConnected() { return isWifiConnected; }

void sendProvisionResponse(const char* status, const char* message = nullptr) {
	if (message) {
		Serial.printf("[WIFI-PROVISION] %s %s\n", status, message);
	} else {
		Serial.printf("[WIFI-PROVISION] %s\n", status);
	}
}

void WiFiNetwork::setWiFiCredentials(const char* SSID, const char* pass) {
	stopProvisioning();
	setStaticIPIfDefined();
	wifiHandlerLogger.info("Connecting to WiFi with credentials (length %d)", pass ? strlen(pass) : 0);
	WiFi.begin(SSID, pass);
	// Reset state, will get back into provisioning if can't connect
	hadWifi = false;
	wifiState = SLIME_WIFI_SERVER_CRED_ATTEMPT;
	wifiConnectionTimeout = millis();
}

IPAddress WiFiNetwork::getAddress() { return WiFi.localIP(); }

void WiFiNetwork::setUp() {
	wifiHandlerLogger.info("Setting up WiFi");
	WiFi.persistent(true);
	WiFi.mode(WIFI_STA);
#if ESP8266
#if USE_ATTENUATION
	WiFi.setOutputPower(20.0 - ATTENUATION_N);
#endif
	WiFi.setPhyMode(WIFI_PHY_MODE_11N);
#endif
	WiFi.hostname("SlimeVR FBT Tracker");
	wifiHandlerLogger.info(
		"Loaded credentials for SSID '%s' and pass length %d",
		WiFi.SSID().c_str(),
		WiFi.psk().length()
	);
	setStaticIPIfDefined();
	wl_status_t status = WiFi.begin(
	);  // Should connect to last used access point, see
		// https://arduino-esp8266.readthedocs.io/en/latest/esp8266wifi/station-class.html#begin
	wifiHandlerLogger.debug("Status: %d", status);
	wifiState = SLIME_WIFI_SAVED_ATTEMPT;
	wifiConnectionTimeout = millis();

#if ESP8266
#if POWERSAVING_MODE == POWER_SAVING_NONE
	WiFi.setSleepMode(WIFI_NONE_SLEEP);
#elif POWERSAVING_MODE == POWER_SAVING_MINIMUM
	WiFi.setSleepMode(WIFI_MODEM_SLEEP);
#elif POWERSAVING_MODE == POWER_SAVING_MODERATE
	WiFi.setSleepMode(WIFI_MODEM_SLEEP, 10);
#elif POWERSAVING_MODE == POWER_SAVING_MAXIMUM
	WiFi.setSleepMode(WIFI_LIGHT_SLEEP, 10);
#error "MAX POWER SAVING NOT WORKING YET, please disable!"
#endif
#else
#if POWERSAVING_MODE == POWER_SAVING_NONE
	WiFi.setSleep(WIFI_PS_NONE);
#elif POWERSAVING_MODE == POWER_SAVING_MINIMUM
	WiFi.setSleep(WIFI_PS_MIN_MODEM);
#elif POWERSAVING_MODE == POWER_SAVING_MODERATE \
	|| POWERSAVING_MODE == POWER_SAVING_MAXIMUM
	wifi_config_t conf;
	if (esp_wifi_get_config(WIFI_IF_STA, &conf) == ESP_OK) {
		conf.sta.listen_interval = 10;
		esp_wifi_set_config(WIFI_IF_STA, &conf);
		WiFi.setSleep(WIFI_PS_MAX_MODEM);
	} else {
		wifiHandlerLogger.error("Unable to get WiFi config, power saving not enabled!");
	}
#endif
#endif
}

void onConnected() {
	WiFiNetwork::stopProvisioning();
	statusManager.setStatus(SlimeVR::Status::WIFI_CONNECTING, false);
	isWifiConnected = true;
	hadWifi = true;
	sendProvisionResponse("CONNECTED", WiFi.localIP().toString().c_str());
	wifiHandlerLogger.info("Connected successfully, IP address %s", WiFi.localIP().toString().c_str());
}

uint8_t WiFiNetwork::getWiFiState() { return wifiState; }

void WiFiNetwork::upkeep() {
	upkeepProvisioning();
	if (WiFi.status() != WL_CONNECTED) {
		if (isWifiConnected) {
			wifiHandlerLogger.warn("Connection to WiFi lost, reconnecting...");
			isWifiConnected = false;
		}
		statusManager.setStatus(SlimeVR::Status::WIFI_CONNECTING, true);
		reportWifiError();
		if (wifiConnectionTimeout + 11000 < millis()) {
			switch (wifiState) {
				case SLIME_WIFI_NOT_SETUP:  // Wasn't set up
					return;
				case SLIME_WIFI_SAVED_ATTEMPT:  // Couldn't connect with first set of
												// credentials
#if ESP8266
					// Try again but with 11G but only if there are credentials,
					// otherwise we just waste time before switching to hardcoded
					// credentials.
					if (WiFi.SSID().length() > 0) {
#if USE_ATTENUATION
						WiFi.setOutputPower(20.0 - ATTENUATION_G);
#endif
						WiFi.setPhyMode(WIFI_PHY_MODE_11G);
						setStaticIPIfDefined();
						WiFi.begin();
						wifiConnectionTimeout = millis();
					wifiHandlerLogger.error(
						"Can't connect from saved credentials, status: %d (SSID: %s, PSK length: %d)",
						WiFi.status(),
						WiFi.SSID().c_str(),
						WiFi.psk().length()
					);
					wifiHandlerLogger.debug(
						"Trying saved credentials with PHY Mode G... (SSID: %s)",
						WiFi.SSID().c_str()
					);
					} else {
						wifiHandlerLogger.debug(
							"Skipping PHY Mode G attempt on 0-length SSID..."
						);
					}
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

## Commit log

2024-05-29 FEAT: update finish rev1 on board
    [SlimeVRDiyModular.brd, SlimeVRDiyModular.sch]
2024-05-30 FEAT: update 3D model, gerber and BOM
    [BOM_SlimeVRDiyModular.csv, SlimeVRDiyModular.brd, SlimeVRDiyModular.sch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]
2024-05-31 DOC: add Dimesion and SCH
    [ERJ-S03F4022V.stp, JST - PH - Thru (V) - 4Pin - 2.00mm.stp, LT3001ES5#TRPBF.stp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]
2024-06-18 FIX: fix problem on pcb
    [SlimeVRDiyModularV2.brd, SlimeVRDiyModularV2.sch, SlimeVRDiyModularV2_production.brd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]
2024-06-28 FIX: fix miss on pcb and update gerber and schematic
    [SlimeVRDiyModularV2.sch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]
2024-06-29 FEAT: add firmware
    [Configuration.h]
2024-06-29 FEAT: firmware setup based on base hardware
    [Configuration.h]
2024-07-17 FEAT: add dimension with case
2024-07-17 FEAT: add 3d file case
    [bottom_case_slimeVR.stl, dumy_battery_slimeVR.stl, spacer_battery_slimeVR.stl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]
2024-07-17 DOC: update readme add 3d case link
2024-11-29 FIX: fix wrong item , cap to res for pulldown the mosfet on psu source
2025-02-15 FEAT: update case after trial 1
    [bottom_case_slimeVR.stl, top_case_slimeVR.3mf, top_case_slimeVR.stl]
2025-09-04 FEAT: testing for current PCB
    [Configuration.h]
2026-08-22 battery: fix voltage divider for R1=1k, R2=1.82k, add debug log
    - Update battery voltage divider resistors to 1k (GND) and 1.82k (battery)
    - Fix ADCMultiplier to use float division
    - Add serial debug log for ADC readings
    - Update WiFi credentials to IOTech1 network
    [batterymonitor.cpp, batterymonitor.h, defines.h]
2026-08-22 fix(firmware): harden WiFi provisioning
    - Comment out hardcoded WiFi credentials in platformio.ini
    - Fix ESP32 SLIME_WIFI_SERVER_CRED_ATTEMPT retry state
    - Add fallback to SLIME_WIFI_SERVER_CRED_G_ATTEMPT for ESP32
    - Keep hardware defines intact (BMI160, rotation, battery divider)
    ## Testing
    - Build verified: pio run -e esp32 (91.6% flash, 14.8% RAM)
    - Serial provisioning command: SET BWIFI <B64SSID> <B64PASSWORD>
    [wifihandler.cpp]
2026-08-22 fix(firmware): improve WiFi debug logging
    - Show SSID being connected in setWiFiCredentials()
    - Add SSID/PSK length to connection error logs
    - Log WiFi status codes for easier troubleshooting
    [wifihandler.cpp]
2026-08-22 fix(web): improve serial connection handling and add status indicators
    - Add badge indicators for Serial and Firmware status
    - Add manual 'Connect USB Serial' button with browser port picker
    - Stream serial log lines from tracker directly to status log UI
    - Handle serial port re-connection gracefully after flashing
2026-08-22 feat(web): add persistent top status bar with serial connection button
2026-08-22 fix(web): make navigation buttons and step rail 100% reliable with direct inline handlers
2026-08-22 refactor(web): fix critical bugs from code review
    - Declare let currentState to avoid strict-mode ReferenceError
    - Remove dead code: sendSerialCommand, readSerialResponse, encodeBase64, decodeBase64, btn-inspect handler
    - Remove duplicate showStep definition (already defined in head)
    - Replace hardcoded #ef4444 with var(--danger)
    - Wrap serial reader loops in try/catch to handle cancel race
    - Remove duplicate navigation event listeners (DOMContentLoaded + direct bind)
2026-08-22 fix(firmware+web): critical bugs from QC review
    firmware: serialcommands.cpp
    - Change && to || in SET WIFI length checks so either field
    over limit triggers reject instead of requiring both invalid
    web: site/index.html
    - Strip inline onclick from step rail + nav buttons, rely solely
    on addEventListener (was double-firing nav)
    - Remove dead code: unused isFirmwareFlashed, logToVerifyLog, encodeBase64,
    decodeBase64, manifest object, duplicate @keyframes pulse injection,
    unused DOM refs (stepItems, stepContents, wifiForm, verifyLog, btnReset)
    - Wrap serial reader loop in try/finally so 10s timeout always cleared
    even when loop breaks from error
    - Add no-acknowledgment warning in fina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
2026-08-22 feat(web): hide top serial button on Flash step; add step 5 Serial Log
    - Hide top Connect Serial button on step 1 (Flash Firmware) since that step uses ESP Web Tools modal exclusively. Re-shown on every other step as global connect toggle.
    - Add step 5 Serial Log with live pre-element streaming tracker USB serial output at 115200 baud. Buttons: Start/Stop Streaming, Clear, Auto-scroll toggle. Read-only, no commands sent.
    - Wrap window.showStep in hook so top-serial visibility toggles on every navigation, and streaming auto-stops when user leaves step 5.
    - Bounded log buffer at 256 KB to prevent OOM on runaway trackers.
2026-08-22 refactor(web): remove redundant in-card nav buttons; keep top serial everywhere
    The step rail already provides navigation across all 5 steps, making
    the in-card Next/Back/Skip buttons redundant clutter. Removed:
    - Step 0 (Inspect): btn-skip-to-flash, btn-skip-to-wifi
    - Step 1 (Flash): btn-goto-wifi, btn-back-to-inspect
    - Step 2 (WiFi): btn-back-to-flash
    Removed matching click handlers and STEPS_WITHOUT_TOP_SERIAL hide rule;
    top Connect Serial button now stays visible on every step as a global
    toggle, consistent across all pages.
2026-08-22 feat(site): flash button reuses open serial port
    Replace <esp-web-install-button> with a plain button that constructs
    <ewt-install-dialog> directly using the already-open port from the top
    Connect Serial toggle. No second port picker on the Flash step.
    When the user has not connected serial, clicking Flash focuses and
    pulses the top Connect Serial button instead of opening a port chooser.
    Load the dialog module via direct import so the custom element is
    registered even without <esp-web-install-button>.
2026-08-22 style(site): rename flash button to 'Flash SlimeVR BMI160 Tracker'
2026-08-22 feat(site): rewrite 'Install' button label to 'Flash SlimeVR BMI160 Tracker'
    The esp-web-tools install dialog hardcodes 'Install' + manifest.name in
    its Lit template. Hook the ewt-install-dialog prototype updated()
    lifecycle and rewrite text nodes after each render so the primary
    action button reads 'Flash SlimeVR BMI160 Tracker' instead.
    Only the exact phrase 'Install SlimeVR BMI160 Tracker' is rewritten, so
    verbs like 'before installing' and the success message 'Installation
    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
2026-08-22 fix(site): manual bootloader reset before esptool flash
    esp-web-tools library hardcodes classic reset polarity (DTR/RTS pulse tuned for CH340). Some auto-downloader boards ignore it and end up flashing to running app instead of bootloader. Patch _confirmInstall prototype to do standard esptool.py sequence (DTR low -> RTS high -> DTR high -> RTS low) before delegating. Also stop any active log stream so flash transport can grab the port.
2026-08-22 fix(site): skip Improv init, add diagnostics, update manifest
    Set new_install_improv_wait_time:0 to skip Improv Serial initialization (SlimeVR firmware not Improv-compatible). Add verbose console.log in bootloader reset patch for debugging. This fixes 'Failed to initialize' + 'stuck at preparing installation' on auto-downloader boards.
2026-08-22 feat(web): package ESP32 firmware for web flashing
    Implement firmware packaging script to merge ESP32 binaries, add manifest with merged binary at offset 0, include SHA-256 checksum, and update site files in dist/ for GitHub Pages deployment.
2026-08-22 refactor(ui): add Positron Elektronik branding with logo and theme
    Add Positron Elektronik logo to header, technical tags for MCU/IMU/LINK, and Positron background texture as subtle overlay while maintaining hardware tool aesthetic.
2026-08-23 fix(ui): positron background asset path; remove broken pages workflow and tracked dist artifacts
    Background url('../assets/positron.jpg') was resolving wrong under GitHub Pages root (resolves to /assets outside the project path). Swapped to './assets/positron.jpg' so /styles.css reads /assets/positron.jpg. Removed .github/workflows/pages.yml (action SHAs invalid, repeated failure on every run). Removed tracked dist/ and site/firmware/ from git; added .gitignore so generated artifacts stay out of the repo. deploy-pages.yml continues to publish site/ directly. After merge, GitHub Pages will rebuild and show the Positron PCB background.
2026-08-23 feat(ui): add Positron brand-logo markup and EWT install patches to site/index.html
    site/index.html had no <img class=brand-logo> markup even though site/styles.css referenced it and site/assets/logo_positron.png existed. Without the markup, the brand row rendered as bare text against the dark theme and the page looked broken once the stylesheet forced the Positron palette. This commit restores the header layout: logo image, brand-info wrapper with subtitle, and brand-tags MCU/IMU/LINK row. Also adds the ESP Web Tools installation module bootstrap plus the ewt-install-dialog patches that rename the EWT button to 'Flash SlimeVR BMI160 Tracker' and force a manual DTR/RTS reset sequence before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
2026-08-23 fix: clean script conflicts, wire flash button to ESP Web Tools, polish missing ink tokens
    scripts/prepare_pages.py and scripts/verify_release.py had unresolved git conflict markers from earlier corruption. Replaced both files with the canonical version (origin/main shape) so packaging and verification run cleanly. Remove deploy-pages.yml which duplicated infrastructure and only shipped raw site/; replaced by pages.yml (firmware build -> prepare_pages -> verify_release -> GH Pages artifact) per WEB_FLASHER_IMPLEMENTATION_PLAN.md sections 11.1-11.4. site/index.html: replace decorative #btn-flash-firmware with <esp-web-install-button manifest=manifest.json> using slot=activate for our branded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
2026-08-23 fix(workflow): stage .pio-staging under firmware working dir
2026-08-23 fix(workflow): use absolute paths for stage since working-dir does not persist between steps
2026-08-23 fix(workflow): enable include-hidden-files and add ls -la debug for staging dir
2026-08-23 fix(ui): wire styles.css + dedupe app.js (root cause of white-bg / no-logo)
2026-08-23 polish(ui): elevate typography, depth, focus rings, status chips, PCB accents
2026-08-23 feat(site): hero CTA + KPI dashboard + lift container to 1400px
    - wider container, kills clutter positron.jpg bg, adds radial+grid backdrop
    - step-1 reborn as hero CTA card: logo + chip row + two-line flash button + browse link
    - step-0 picks up KPI row (USB/Port/Firmware/Browser) wired in app.js
    - step rail gets panel + 'Workflow' header + active red gradient (signal no longer washed out)
    - btn-primary red->positron gradient (signal now reserved for system OK states)
    - step-title --t-2xl + accent bar glow
    breaking visual jump: every step now reads as a distinct product surface
2026-08-23 feat(site): rewrite installer UI to production-grade Positron workspace
    - reset styles.css to single coherent architecture (167 rules, ~700 lines): tokens, reset, shell, header, status bar, main grid, rail, step panels, flash hero, form, log, terminal, btn system, responsive, prefers-reduced-motion
    - rewrite index.html with semantic class names only (no inline color styles); DOM contract preserved for app.js
    - rewrite app.js state model: class-based status helpers (setStatusDotClass, setTileClass, setKpiState), goToStep single source of truth for step navigation, hash-aware boot
    - add Playwright QA harness (scripts/visual-qa/): 4 viewports x 5 steps, full-page screenshot, computed style d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
2026-08-23 feat(site): production-grade Positron installer rewrite + CI/QA tooling (#13)
    * feat(site): rewrite installer UI to production-grade Positron workspace
    - add Playwright QA harness (s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
2026-08-23 fix(wifi): add phase banner + spinner feedback during credentials save
    - wifi-phase banner shows idle/connecting/handshake/sending/success/error states
    - Save button: disabled with spinner text while processing, restore after success/failure
    - Retry/Reconfigure buttons replace Save after operation completes
    - Banner color: red (processing) → green (success) → red (error)
    - Pulse animation on processing dot, static on success/error
2026-08-23 fix(serial): add Start streaming button handler
    - add startSerialLog(): open serial port @ 115200 baud, decode stream, append to live-log
    - add stopSerialLog(): cancel reader, reset button text/icon
    - add setupSerialLog(): wire Start/Stop/Clear buttons + auto-scroll toggle
    - update log-status with state messages (Streaming started / Stopped / Error)
2026-08-24 docs(hardware): add hardware overview section with images
    PCB renders, 3D case, assembled photos, finished product gallery. Component table from BOM. Regenerated PDF.
2026-08-24 docs(hardware): simplify to 2 images with detailed descriptions
    Keep only slimeVR_real_5 (product components) and slimeVR_5 (PCB pinout). Add page-break CSS to prevent title/image split across PDF pages.
2026-08-24 feat(site): add documentation step with hardware overview
    Step 06 in web installer shows product components and PCB pinout. Update smoke test sentinel count for 6 step-panels.

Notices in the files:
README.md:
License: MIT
